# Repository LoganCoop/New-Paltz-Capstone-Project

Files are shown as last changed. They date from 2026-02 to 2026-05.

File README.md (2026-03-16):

# New Paltz Capstone Project – LiDAR Scanner

## Project Ideas
**Date:** 1/21/2026

## Initial Idea
**LiDAR Scanner – Physical Computing**
- Raspberry Pi – Python or Arduino – C++
- Made for room scanning
- Environmental mapping
- Handheld and/or mobile
- 3D printed parts

## Overview
My current idea for the student-proposed project will be a LiDAR scanner that I will build and program myself. I want to use Arduino and/or Raspberry Pi parts for the hardware, as well as 3D printed parts to create housing for the Arduino components. I intend to write the software myself for the LiDAR mapping using the C++-based Arduino language, and/or using Python via a Raspberry Pi. As an add-on to this project, I'd like to make the scanner mobile if I have the time to do so, whether it is done via a drone or a handheld scanner. I believe that this project is a great blend of software and hardware and that it would be a great opportunity to develop my skills in combining both fields of technology. I personally have great experience with CAD and 3D printing, as well as all of the material I have covered during my time working on my computer science degree, so I believe this project would be a great way to improve and show my skills.

## Project Scope
1. **Coordinate Transformation:** Implementing the trigonometric algorithms necessary to map 1D distance readings into 3D space.
2. **Hardware-Software Integration:** Managing the “logic flow” between physical movement (motors) and data acquisition (sensors) to ensure sub-centimeter accuracy.
3. **Signal Processing:** Implementing filters to reduce sensor noise and handle “outlier” data points in complex environments.
4. **Mobility (Stretch Goal):** If time permits, the system will be adapted into a handheld form factor using an IMU (Inertial Measurement Unit) to allow for mobile scanning (SLAM – Simultaneous Localization and Mapping).
	- A Pi Camera 3 can be used for marker-based localization to reduce drift.

## Timeline Layout
- **Phase 1:** Component testing and basic 2D mapping.
- **Phase 2:** Integration of the Godot visualization and 3D data collection.
- **Phase 3:** Refinement of the visualization UI and final housing assembly.

## Initial TF-Luna UART Test
This project includes a small Python script to read TF-Luna frames over UART and print
distance data for quick sensor validation.

### Wiring Notes (TF-Luna to Raspberry Pi)
- Connect GND to GND.
- Connect TF-Luna TX to Pi RX (GPIO 15).
- Connect TF-Luna RX to Pi TX (GPIO 14).
- Provide 5V power to the TF-Luna (verify your model's voltage/logic levels in its datasheet).

### Setup
1. Enable the Pi UART (raspi-config) and reboot.
2. Install dependencies:
	- `python -m pip install -r requirements.txt`
3. Run the reader:
	- `python tools/tfluna_read.py --port /dev/serial0 --baud 115200`

### Output
Each line includes a timestamp, distance in cm, signal strength, and temperature in C.

## Initial BNO055 Quaternion Test
This project includes a small Python script to read BNO055 quaternion output over I2C.

### Wiring Notes (BNO055 to Raspberry Pi)
- Connect GND to GND.
- Connect VIN to 3.3V or 5V (check your board's regulator specs).
- Connect SDA to GPIO 2 (SDA).
- Connect SCL to GPIO 3 (SCL).

### Setup
1. Enable I2C on the Pi (raspi-config) and reboot.
2. Install dependencies:
	- `python -m pip install -r requirements.txt`
3. Run the reader:
	- `python tools/bno055_quat_read.py --address 0x28 --rate 10`

### Output
Each line includes a timestamp and quaternion components (qw, qx, qy, qz).

## Pi Prep Checklist
- Update packages and reboot after updates.
- Enable UART (disable serial console), I2C, and Camera in raspi-config.
- Install base tools: python3-venv, python3-pip, i2c-tools, libcamera-apps.
- Add your user to dialout for serial access and log out/in.

## Pi Camera 3 Tests and Marker Localization
Marker-based localization uses the Pi Camera 3 to detect known visual markers and provide
absolute reference points, which helps reduce drift compared to IMU-only integration.

### Camera Test
1. Install camera tools:
	- `sudo apt install -y python3-picamera2 libcamera-apps`
2. Run the test capture:
	- `python tools/camera_test.py --output camera_test.jpg`

### ArUco Marker Demo
1. Install dependencies:
	- `sudo apt install -y python3-opencv python3-picamera2`
2. Run marker detection:
	- `python tools/aruco_pose_demo.py --rate 10`

---

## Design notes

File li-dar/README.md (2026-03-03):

# LiDAR Quest 3 VR Point Cloud Visualization

This is a **Godot 4.x** project for visualizing LiDAR point clouds in VR using the Meta Quest 3 headset.

## 🎯 Purpose

This VR application replaces the original PiCam 3 approach with Quest 3's superior tracking capabilities, allowing for more accurate and immersive 3D point cloud visualization.

## 📁 Project Structure

```
li-dar/
├── materials/              # Custom materials for rendering
│   └── point_cloud_material.tres
├── scenes/                 # Godot scene files
│   └── main_vr.tscn       # Main VR scene
├── scripts/                # GDScript files
│   ├── lidar_udp_receiver.gd
│   ├── point_cloud_visualizer.gd
│   └── vr_controller.gd
├── shaders/                # Custom shaders
│   └── point_cloud.gdshader
├── icon.svg                # Project icon
├── project.godot           # Godot project configuration
├── QUEST3_VR_SETUP_GUIDE.md    # Complete setup instructions
└── QUEST3_QUICK_START.md        # Quick start checklist
```

## 🚀 Quick Start

1. **Install Godot 4.3+** from [godotengine.org](https://godotengine.org)
2. **Open this project** in Godot
3. **Connect Quest 3** via USB (Developer Mode enabled)
4. **Export to Quest 3** (Project → Export → Android)
5. **Run Python sensor scripts** from parent directory
6. **Launch the app** on Quest 3

**Full instructions**: See [QUEST3_VR_SETUP_GUIDE.md](QUEST3_VR_SETUP_GUIDE.md)

## 🎮 Features

- ✅ Real-time LiDAR point cloud visualization in VR
- ✅ UDP receiver for TFLuna + BNO055 sensor data
- ✅ Mesh-based rendering (up to 50,000 points)
- ✅ Spatial deduplication for cleaner clouds
- ✅ Color-coded distance visualization
- ✅ VR controller support for navigation
- ✅ 6DOF tracking using Quest 3
- ✅ 90Hz refresh rate
- ✅ Custom point cloud shader

## 🔗 How It Connects to Parent Project

This Godot project receives data from:
- **`tools/send_sensor_data_udp.py`** - Sends sensor data via UDP
- **`hal/`** - Hardware abstraction layer for sensors
- **TFLuna LiDAR sensor** - Distance measurements
- **BNO055 IMU** - Orientation quaternions

## 🛠️ Requirements

- **Meta Quest 3** VR headset
- **Godot 4.3+**
- **Android SDK & NDK**
- **Python 3.x** (for sensor scripts)
- **WiFi network** (PC and Quest 3 must be on same network)

## 📚 Documentation

- **[QUEST3_VR_SETUP_GUIDE.md](QUEST3_VR_SETUP_GUIDE.md)** - Complete setup guide
- **[QUEST3_QUICK_START.md](QUEST3_QUICK_START.md)** - Quick start checklist
- **[../UNITY_SETUP_GUIDE.md](../UNITY_SETUP_GUIDE.md)** - Original Unity version (alternative)

## 🎨 Customization

### Change Point Size
Edit `shaders/point_cloud.gdshader`:
```gdshader
uniform float point_size = 8.0;  // Change this value
```

### Change Colors
Edit `scripts/point_cloud_visualizer.gd`:
```gdscript
@export var min_color: Color = Color(0, 0, 1)  # Blue
@export var max_color: Color = Color(1, 0, 0)  # Red
```

## 🐛 Troubleshooting

**No points appearing?**
- Check UDP port 5005 is open in firewall
- Verify Python scripts are running
- Ensure PC and Quest 3 are on same WiFi

**Low frame rate?**
- Reduce `max_points` to 30000
- Increase `voxel_size` to 0.05
- Disable deduplication temporarily

**App crashes?**
- Check Godot console for errors
- Verify Android export templates installed
- Update Quest 3 firmware

## 🎯 Advantages Over Unity/PiCam Approach

1. **No camera required** - Uses Quest 3's built-in tracking
2. **More accurate** - Inside-out tracking beats IMU-only
3. **Real-time immersion** - See the scan as you create it
4. **6DOF freedom** - Walk around the point cloud
5. **No Aruco markers** - Simpler setup
6. **Higher refresh** - 90Hz vs typical 60Hz

## 📊 Performance

- **Target**: 90 FPS on Quest 3
- **Max Points**: 50,000 (configurable)
- **Latency**: < 50ms from sensor to display
- **Resolution**: 1832×1920 per eye

## 🔮 Future Enhancements

- [ ] Point cloud export to PLY/OBJ
- [ ] Multiple TFLuna sensor support
- [ ] Hand tracking instead of controllers
- [ ] Spatial anchors for persistent clouds
- [ ] WiFi direct instead of UDP broadcast

---

**Created**: March 2026  
**Godot Version**: 4.3+  
**Target Platform**: Meta Quest 3 (Android)  
**License**: See parent project

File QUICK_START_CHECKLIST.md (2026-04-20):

# 🎯 Unity LiDAR Scanner - Quick Start Checklist

Follow these steps in order. Check off each step as you complete it.

## ☑️ Phase 1: Project Setup (5 minutes)

- [ ] Open Unity Hub
- [ ] Create new 3D project OR open existing project
- [ ] Create folder structure:
  - [ ] Assets/Scripts/
  - [ ] Assets/Shaders/
  - [ ] Assets/Materials/
  - [ ] Assets/Prefabs/
  - [ ] Assets/Scenes/

## ☑️ Phase 2: Import Files (3 minutes)

- [ ] Copy `LidarUdpReceiver.cs` → `Assets/Scripts/`
- [ ] Copy `SimpleCamera.cs` → `Assets/Scripts/`
- [ ] Copy `PointCloud.shader` → `Assets/Shaders/`
- [ ] Wait for Unity to compile (check bottom-right progress bar)
- [ ] Verify no errors in Console window (Ctrl+Shift+C)

## ☑️ Phase 3: Create Materials (2 minutes)

- [ ] Navigate to `Assets/Shaders/` in Project window
- [ ] Right-click `PointCloud.shader` → Create → Material
- [ ] Rename material to: `PointCloudMaterial`
- [ ] Select material, set in Inspector:
  - [ ] Point Size: `8`
  - [ ] Brightness: `1.0`
- [ ] Move material to `Assets/Materials/` folder

## ☑️ Phase 4: Create Point Prefab (3 minutes)
*(Skip if using mesh-based mode)*

- [ ] Hierarchy → Right-click → 3D Object → Sphere
- [ ] Rename to: `LidarPoint`
- [ ] In Inspector, remove Sphere Collider component
- [ ] Drag from Hierarchy → `Assets/Prefabs/` folder
- [ ] Delete from Hierarchy (prefab is saved)

## ☑️ Phase 5: Setup Scene (10 minutes)

### Create Scanner GameObject:
- [ ] Hierarchy → Right-click → Create Empty
- [ ] Rename to: `LidarScanner`
- [ ] Position: `(0, 0, 0)`
- [ ] Add Component → `LidarUdpReceiver`

### Configure LidarUdpReceiver:
- [ ] **Port**: `5005`
- [ ] **Point Prefab**: Drag from Prefabs folder *(optional)*
- [ ] **Scale Meters**: `0.01`
- [ ] **Point Scale**: `0.02`
- [ ] **Max Points**: `50000`

#### Distance Gradient:
- [ ] Click gradient bar
- [ ] Add color stops:
  - [ ] Left (0%) = Blue
  - [ ] Middle (50%) = Green  
  - [ ] Right (100%) = Red

#### Settings:
- [ ] **Min Distance Meters**: `0.1`
- [ ] **Max Distance Meters**: `5.0`
- [ ] **Min Strength**: `100`
- [ ] **Distance Median Window**: `5`
- [ ] **Orientation Smoothing**: `0.5`

#### Checkboxes:
- [ ] ✅ Use Pos Field
- [ ] ✅ Debug Overlay
- [ ] ✅ Data Already In Unity Frame
- [ ] ⬜ Flip X
- [ ] ⬜ Flip Y
- [ ] ⬜ Swap Y And Z
- [ ] ⬜ Invert Z
- [ ] ⬜ Mirror Horizontal
- [ ] ✅ Use Spatial Deduplication
- [ ] **Voxel Size**: `0.03`
- [ ] ✅ Use Mesh Renderer
- [ ] **Point Cloud Material**: Drag from Materials folder

#### Legacy correction values:
- [ ] **Yaw Correction Degrees**: `0`
- [ ] **Pitch Correction Degrees**: `0`
- [ ] **Roll Correction Degrees**: `0`
- [ ] **Apply Coordinate Correction To Fallback Direction**: unchecked
- [ ] **Invert Fallback Vertical Axis**: unchecked

#### Unity-frame trim (when data is inverted):
- [ ] **Unity Frame Invert X**: checked *(for left/right reversed)*
- [ ] **Unity Frame Invert Y**: checked *(for up/down reversed)*
- [ ] **Unity Frame Invert Z**: unchecked
- [ ] **Unity Frame Yaw Correction Degrees**: `0`
- [ ] **Unity Frame Pitch Correction Degrees**: `0`
- [ ] **Unity Frame Roll Correction Degrees**: `180` *(use this when both left/right and up/down are inverted)*

### Setup Camera:
- [ ] Select `Main Camera` in Hierarchy
- [ ] Position: `(0, 2, -3)`
- [ ] Rotation: `(20, 0, 0)`
- [ ] Background color: Dark gray `(30, 30, 30)`
- [ ] Add Component → `SimpleCamera` *(optional)*

### Lighting:
- [ ] Verify `Directional Light` exists
- [ ] Rotation: `(50, -30, 0)`

### Save Scene:
- [ ] File → Save As → `Assets/Scenes/LidarScanner.unity`

## ☑️ Phase 6: Test Python Connection (5 minutes)

### Start Python Scripts:
- [ ] Open PowerShell/Terminal
- [ ] Navigate to project folder:
  ```powershell
  cd "C:\Users\lpcoo\OneDrive\Desktop\Capstone Project - LiDAR"
  ```
- [ ] Run sensor scripts:
  ```powershell
  python run_all_components.py
  ```
  OR
  ```powershell
  python tools/send_sensor_data_udp.py --ip <QUEST_OR_PC_IP>
  ```
- [ ] Keep the Python sender mount defaults unless you physically remount the IMU/LiDAR assembly.
- [ ] Verify output shows "Sending UDP packets..."

## ☑️ Phase 7: First Test Run! (2 minutes)

- [ ] Press **Play ▶️** in Unity
- [ ] Check top-left overlay shows:
  - [ ] UDP packets count increasing
  - [ ] "Last packet: X.XXs ago" updating
  - [ ] Point count increasing
- [ ] Verify points appearing in Game view
- [ ] Test camera controls (Right-click + WASD)
- [ ] Press Space to calibrate orientation

## ✅ Success Criteria

You should see:
- ✅ Points appearing in 3D space
- ✅ Colors changing by distance (blue → green → red)
- ✅ UDP packet counter increasing
- ✅ No errors in Console
- ✅ Smooth point cloud building up

## ⚠️ Troubleshooting Quick Fixes

| Problem | Solution |
|---|---|
| No packets received | Check Python script is running, port = 5005 |
| No points visible | Check camera position, Material assigned |
| Errors in Console | Read error message, check file paths |
| Performance slow | Decrease maxPoints to 10000, increase voxelSize to 0.05 |
| Points jumping | Increase orientationSmoothing to 0.8 |

## 📚 Full Documentation

For detailed explanations, see:
- `UNITY_SETUP_GUIDE.md` - Complete step-by-step guide
- `MESH_SYSTEM_SETUP.md` - Mesh rendering system details

## 🎮 Controls Reference

### In Unity Editor:
- **Space** - Calibrate sensor orientation
- **Right-Mouse + WASD** - Fly camera
- **E/Q** - Up/Down
- **Shift** - Move faster
- **F** - Focus on selected object

### In Python:
- **Ctrl+C** - Stop sensor scripts

---

**Estimated Total Time: 30 minutes**

**Current Step:** _________

**Notes:**
_______________________________________________________
_______________________________________________________
_______________________________________________________

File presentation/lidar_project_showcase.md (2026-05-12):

---
marp: true
theme: lidar-showcase
paginate: true
size: 16:9
style: |
  section {
    font-size: 28px;
  }
  .tight li {
    margin: 0.12em 0;
  }
  .center {
    text-align: center;
  }
  .label {
    color: #0b5fff;
    font-weight: 700;
    text-transform: uppercase;
    letter-spacing: 0.08em;
    font-size: 0.52em;
  }
---

<!-- _class: lead -->
# Handheld LiDAR Scanner System
## Custom Sensor Build to Point Cloud Visualization

Logan Cooper  
SUNY New Paltz

<div class="callout">
This project combines hardware integration, Python tooling, networking, CAD and 3D printing, and VR rendering into one working spatial scanning pipeline.
</div>

---

# Why This Project Matters

<div class="columns">
<div class="panel">
<div class="label">Core Idea</div>
Build a low-cost handheld system that turns real-world distance samples into a 3D point cloud.

</div>
<div class="panel">
<div class="label">What It Shows</div>
Physical hardware, embedded-style integration, data processing, visualization, and immersive interaction.
</div>
</div>

<div class="metric-row">
<div class="metric"><strong>Hardware</strong> TF-Luna, BNO055, Pi 5, Pi Camera 3, 3D printed housing</div>
<div class="metric"><strong>Software</strong> Python tools, HAL interfaces, Unity and Godot visualization</div>
<div class="metric"><strong>Outcome</strong> Live UDP stream into a 2D and VR point cloud viewer</div>
</div>

---

# What Is LiDAR?

**LiDAR** stands for **Light Detection and Ranging**.

It works by sending out laser pulses and measuring how long they take to return, which gives distance information that can be used to reconstruct the surrounding environment.

<div class="columns">
<div class="panel">
<strong>Common Uses</strong>
<ul>
  <li>Autonomous navigation</li>
  <li>Robotics and mapping</li>
  <li>Surveying and architecture</li>
  <li>AR and VR spatial computing</li>
</ul>
</div>
<div class="panel">
<strong>Why It Fits This Project</strong>
<ul>
  <li>Strong mix of hardware and software</li>
  <li>Clear real-world application</li>
  <li>Good match for CAD and fabrication work</li>
  <li>Expandable toward mobile scanning and SLAM</li>
</ul>
</div>
</div>

---

# Project Story

> The project began as a custom LiDAR scanner concept and evolved into a working end-to-end system that reads sensors on a Raspberry Pi, transforms the data into 3D points, and visualizes the results inside a Unity/Godot environment and soon into a Quest 3 VR application.

---

<!-- _class: section -->
# Build Components
## Hardware and software pieces that make the system work

---

# System Components and Their Roles

| Component | What it does in the project |
|---|---|
| TF-Luna LiDAR | Captures 1D distance samples from the environment |
| BNO055 IMU | Provides quaternion orientation for 3D point transformation |
| Raspberry Pi 5 | Runs the Python code, sensor acquisition, and UDP transmission |
| Pi Camera 3 | Supported calibration and ArUco marker localization experiments |
| 3D printed housing | Turns the electronics into a handheld scanner form factor |
| Unity / Godot | Receives and visualizes live spatial data |
| Meta Quest 3 | Will make the point cloud explorable in immersive VR |

---

# Software Stack

<div class="columns">
<div class="panel">
<strong>Python Side</strong>
<ul>
  <li>Sensor readers for TF-Luna and BNO055</li>
  <li>Test utilities and data output tools</li>
  <li>UDP sender scripts</li>
  <li>HAL interfaces for cleaner integration and mocking</li>
</ul>
</div>
<div class="panel">
<strong>Visualization Side</strong>
<ul>
  <li>Unity for earlier visualization and marker testing</li>
  <li>Godot 4 project for current VR rendering</li>
  <li>Custom point cloud shader and material pipeline</li>
  <li>Quest 3 deployment and debugging workflow</li>
</ul>
</div>
</div>

<div class="callout">
This split was important: the Pi handles sensing and transformation, while the engine handles rendering and user experience.
</div>

---

# Unity Progress (Completed)

<div class="columns">
<div class="panel">
<strong>What I Finished in Unity</strong>
<ul>
  <li>Built UDP data bridge from Raspberry Pi to Unity</li>
  <li>Validated TF-Luna and BNO055 data flow in real time</li>
  <li>Implemented ArUco marker pose streaming into Unity</li>
  <li>Updated receiver to handle both sensor and marker data</li>
</ul>
</div>
<div class="panel">
<strong>Why This Matters</strong>
<ul>
  <li>Proved core scanner pipeline works end-to-end</li>
  <li>Confirmed packet format and transform logic</li>
  <li>Reduced risk before moving to VR deployment</li>
</ul>
</div>
</div>

---

<!-- _class: section -->
# Main Challenge
## Pi Camera 3 integration issues and project pivot

---

# Pi Camera 3 Challenge and Pivot to VR

<div class="columns">
<div class="panel">
<strong>Problem I Ran Into</strong>
<ul>
  <li>Pi Camera 3 setup was inconsistent across packages/drivers</li>
  <li>Marker pipeline added complexity during live integration</li>
  <li>Troubleshooting consumed time better spent on core scanning workflow</li>
</ul>
</div>
<div class="panel">
<strong>Decision and Result</strong>
<ul>
  <li>Kept Unity progress as validated foundation</li>
  <li>Shifted visualization path to Quest 3 VR pipeline</li>
  <li>Simplified interactive inspection of point clouds</li>
</ul>
</div>
</div>

<div class="callout">
The switch to VR was a strategic project decision, not a reset: it built on the data pipeline already proven in Unity.
</div>

---

<!-- _class: section -->
# Construction
## Wiring, CAD, printing, and assembly

---

# How the Scanner Was Built

<div class="columns">
<div>

1. Wire the TF-Luna to the Raspberry Pi over UART.
2. Wire the BNO055 IMU to the Raspberry Pi over I2C.
3. Verify the hardware with isolated test scripts.
4. Design the handheld housing in CAD.
5. 3D print and assemble the casing.
6. Re-test as an integrated scanner system.

</div>
<div>

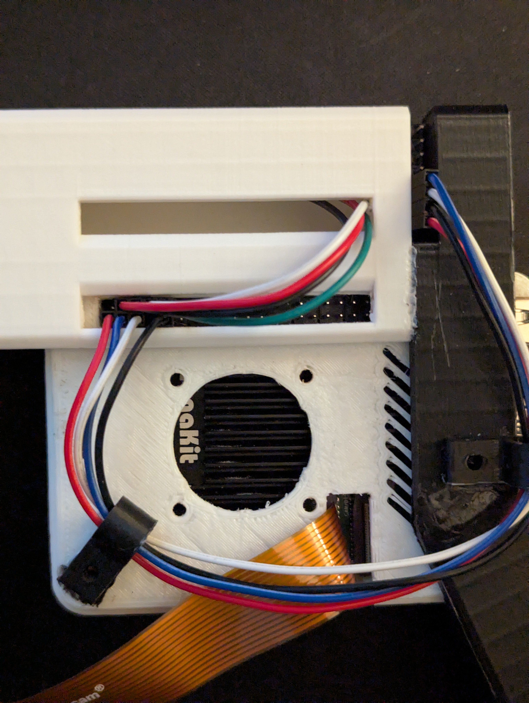
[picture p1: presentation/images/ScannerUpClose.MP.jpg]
height:260px


</div>
</div>

<div class="callout">
The housing design was made to keep sensor alignment stable and make the device practical for handheld scanning.
</div>

---

# Data Pipeline Architecture

```text
TF-Luna distance  ----->
                        Raspberry Pi 5 -----> UDP packets -----> Unity / Godot / Quest 3
BNO055 quaternion ----->
```

<div class="columns">
<div class="panel">
<strong>On the Raspberry Pi</strong>
<ul>
  <li>Read live sensor data</li>
  <li>Pair orientation with distance samples</li>
  <li>Transform measurements into 3D point candidates</li>
</ul>
</div>
<div class="panel">
<strong>In the Visualization Engine</strong>
<ul>
  <li>Receive incoming packets</li>
  <li>Add points to the cloud buffer</li>
  <li>Render them in real time for inspection</li>
</ul>
</div>
</div>

---

<!-- _class: section -->
# Initial Testing
## Proving each part worked before full integration

---

# Testing Approach

The project was built incrementally.

<div class="columns">
<div class="panel tight">
<strong>Hardware Validation</strong>
<ul>
  <li>TF-Luna UART test</li>
  <li>BNO055 quaternion test</li>
  <li>Pi Camera 3 image capture test</li>
  <li>Camera calibration and ArUco experiments</li>
</ul>
</div>
<div class="panel tight">
<strong>Integration Validation</strong>
<ul>
  <li>UDP stream testing</li>
  <li>Unity marker pose visualization</li>
  <li>Transition plan into Godot VR receiver</li>
  <li>Initial Quest 3 pipeline validation</li>
</ul>
</div>
</div>

<div class="callout">
Testing components in isolation first made it easier to find wiring, configuration, and data-format issues quickly.
</div>

---

# Raw Sensor Output Examples

<div class="columns">
<div>

### TF-Luna sample
```text
1770662039.648 dist_cm=0 strength=128 temp_c=39.00
1770662039.658 dist_cm=0 strength=128 temp_c=39.00
1770662039.669 dist_cm=0 strength=131 temp_c=39.00
```

</div>
<div>

### BNO055 sample
```text
1770662963.567 qw=1.000000 qx=0.000000 qy=-0.000061 qz=0.000305
1770662963.669 qw=0.368164 qx=-0.492737 qy=0.788452 qz=0.000122
1770662963.771 qw=0.368164 qx=-0.492737 qy=0.788452 qz=0.000183
```

</div>
</div>

<div class="caption">These logs show the actual raw information the project uses: distance, strength, temperature, and orientation quaternion data.</div>

---

<!-- _class: section -->
# Sending Data
## Bridging the scanner to the visualization environment with UDP

---

# Why UDP Was a Good Fit

<div class="columns">
<div class="panel">
<strong>Advantages</strong>
<ul>
  <li>Lightweight</li>
  <li>Fast for real-time streaming</li>
  <li>Easy to integrate into Unity and Godot</li>
  <li>Good enough even if a small number of packets are lost</li>
</ul>
</div>
<div class="panel">
<strong>What Gets Sent</strong>
<ul>
  <li>Timestamp</li>
  <li>Distance measurements</li>
  <li>Orientation data</li>
  <li>Transformed point information</li>
  <li>Marker or visualization metadata when needed</li>
</ul>
</div>
</div>

```text
Sensor Read -> Orientation Fusion -> Point Transform -> UDP Packet -> Receiver App
```

---

<!-- _class: section -->
# Point Cloud
## Turning sensor samples into a usable 3D representation

---

# System Diagram

<div class="diagram-grid">
<svg viewBox="0 0 1040 600" role="img" aria-label="LiDAR system data flow diagram">
  <defs>
    <marker id="arrow-showcase" viewBox="0 0 10 10" refX="8" refY="5" markerWidth="8" markerHeight="8" orient="auto-start-reverse">
      <path d="M 0 0 L 10 5 L 0 10 z" fill="#3f7bff"></path>
    </marker>
  </defs>

  <rect class="entity" x="24" y="80" width="110" height="46" rx="10"></rect>
  <text x="79" y="109" text-anchor="middle">Operator</text>

  <rect class="entity" x="24" y="430" width="110" height="46" rx="10"></rect>
  <text x="79" y="459" text-anchor="middle">Sensors</text>

  <ellipse class="process" cx="395" cy="90" rx="120" ry="28"></ellipse>
  <text x="395" y="96" text-anchor="middle">Scanner Control</text>

  <ellipse class="process" cx="395" cy="210" rx="132" ry="30"></ellipse>
  <text x="395" y="216" text-anchor="middle">Sensor Read Process</text>

  <ellipse class="process" cx="395" cy="346" rx="132" ry="30"></ellipse>
  <text x="395" y="352" text-anchor="middle">Pose Fusion Process</text>

  <ellipse class="process" cx="395" cy="492" rx="142" ry="30"></ellipse>
  <text x="395" y="498" text-anchor="middle">Point Cloud Rendering</text>

  <rect class="store-body" x="820" y="38" width="130" height="98" rx="2"></rect>
  <ellipse class="store-top" cx="885" cy="38" rx="65" ry="18"></ellipse>
  <ellipse class="store-top" cx="885" cy="136" rx="65" ry="18"></ellipse>
  <text x="885" y="46" text-anchor="middle">Control State</text>

  <rect class="store-body" x="780" y="168" width="170" height="130" rx="2"></rect>
  <ellipse class="store-top" cx="865" cy="168" rx="85" ry="22"></ellipse>
  <ellipse class="store-top" cx="865" cy="298" rx="85" ry="22"></ellipse>
  <text x="865" y="175" text-anchor="middle">Raw Scan Samples</text>

  <rect class="store-body" x="810" y="330" width="140" height="104" rx="2"></rect>
  <ellipse class="store-top" cx="880" cy="330" rx="70" ry="19"></ellipse>
  <ellipse class="store-top" cx="880" cy="434" rx="70" ry="19"></ellipse>
  <text x="880" y="337" text-anchor="middle">Pose Records</text>

  <rect class="store-body" x="790" y="466" width="160" height="112" rx="2"></rect>
  <ellipse class="store-top" cx="870" cy="466" rx="80" ry="21"></ellipse>
  <ellipse class="store-top" cx="870" cy="578" rx="80" ry="21"></ellipse>
  <text x="870" y="473" text-anchor="middle">Point Cloud Buffer</text>

  <path class="connector" d="M 134 103 C 205 103, 250 95, 276 92" marker-end="url(#arrow-showcase)"></path>
  <path class="connector" d="M 134 103 C 205 115, 250 178, 263 205" marker-end="url(#arrow-showcase)"></path>
  <path class="connector" d="M 134 103 C 205 145, 244 430, 252 486" marker-end="url(#arrow-showcase)"></path>

  <path class="connector" d="M 134 453 C 205 453, 243 436, 257 358" marker-end="url(#arrow-showcase)"></path>
  <path class="connector" d="M 134 453 C 215 453, 238 483, 251 492" marker-end="url(#arrow-showcase)"></path>

  <path class="connector" d="M 515 90 C 635 90, 712 90, 820 64" marker-end="url(#arrow-showcase)"></path>
  <path class="connector" d="M 527 210 C 637 210, 701 210, 780 233" marker-end="url(#arrow-showcase)"></path>
  <path class="connector" d="M 527 346 C 636 346, 716 346, 810 382" marker-end="url(#arrow-showcase)"></path>
  <path class="connector" d="M 537 492 C 634 492, 708 500, 790 520" marker-end="url(#arrow-showcase)"></path>

  <path class="connector" d="M 820 120 C 714 130, 618 180, 515 205" marker-end="url(#arrow-showcase)"></path>
  <path class="connector" d="M 790 520 C 708 512, 618 438, 515 358" marker-end="url(#arrow-showcase)"></path>
  <path class="connector" d="M 810 382 C 714 386, 621 448, 525 487" marker-end="url(#arrow-showcase)"></path>
</svg>
</div>

<div class="callout">
This version frames the project as a data-flow system: external inputs feed processing stages, which update stored scan state and the final point cloud buffer.
</div>

---

# VR Transition

<div class="columns">
<div class="panel">
<strong>Earlier Stage</strong>
<ul>
  <li>Unity-based environment</li>
  <li>Marker pose visualization</li>
  <li>Desktop validation of data flow</li>
  <li>Good for early debugging and proof of concept</li>
</ul>
</div>
<div class="panel">
<strong>Current Direction</strong>
<ul>
  <li>Dedicated Godot VR pipeline</li>
  <li>Quest 3 deployment workflow</li>
  <li>In-headset point cloud viewing</li>
  <li>Focused scan analysis in VR</li>
</ul>
</div>
</div>

---

# Why VR Still Improves the Project

- Depth is easier to understand in an immersive 3D view.
- You can move around the point cloud naturally.
- It is easier to notice gaps, noise, and structure.
- It builds directly on the Unity-validated data pipeline.

---

# Housing Design and Assembly

<div class="columns">
<div>

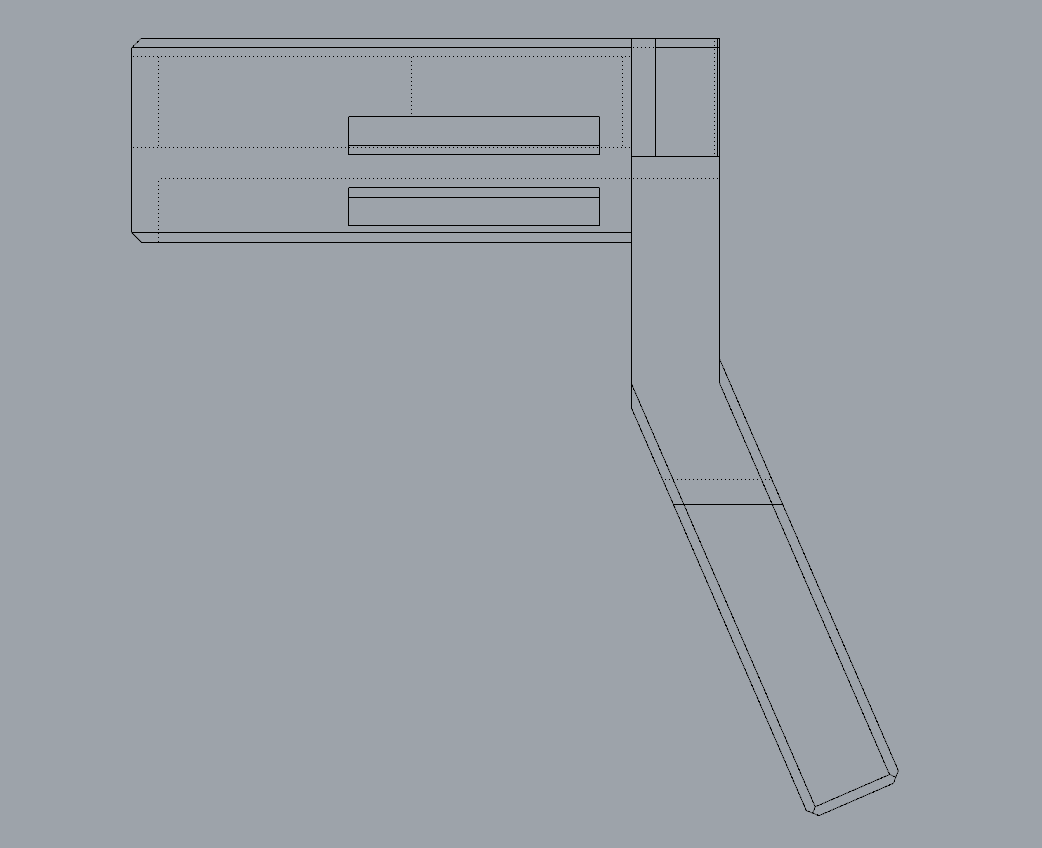
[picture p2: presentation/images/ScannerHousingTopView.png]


</div>
<div>

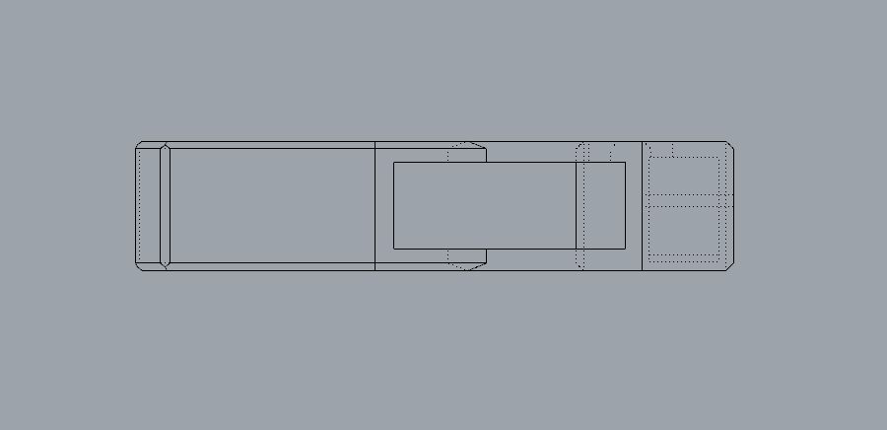
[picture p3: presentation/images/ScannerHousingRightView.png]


</div>
</div>

- Front, top, and side housing views were used to verify fit and assembly clearances.
- The enclosure organizes TF-Luna, BNO055, and Raspberry Pi mounting points.
- Mechanical alignment improved repeatability during scan motion.
- CAD to print to test iteration shortened integration time.

<div class="caption">The 3D-printed housing acts as the mechanical backbone of the handheld scanner.</div>

---

# Project Timeline and Growth

| Date | Milestone |
|---|---|
| 1/21/26 | Initial project idea and scope defined |
| 2/5/26 | Planned addition of IMU, camera, and integration hardware |
| 2/6/26 | Core components assembled and initial testing underway |
| 2/9/26 | Housing design and Unity bridge work began |
| 2/12/26 | Pi Camera 3 calibration and ArUco pose streaming to Unity completed |
| 3/3/26 | Switched to dedicated Godot Quest 3 VR pipeline |
| 3/10/26 | Added VR scripts, Quest deployment flow, and improved point cloud rendering |

---

<!-- _class: section -->
# Conclusion
## What this project demonstrates today

---

# What This Project Already Achieved

- Built a custom handheld LiDAR scanner system from separate components
- Combined hardware, Python tooling, networking, CAD, and 3D visualization
- Created a working live Unity pipeline from sensors to point cloud display
- Identified and handled integration challenges (including Pi Camera 3 issues)
- Established a clear transition path from Unity validation to VR interaction

---

# Next Steps

<div class="columns">
<div class="panel">
<strong>Technical Improvements</strong>
<ul>
  <li>Finalize end-to-end Quest 3 benchmark</li>
  <li>Add point cloud export support</li>
  <li>Continue filtering/calibration improvements</li>
</ul>
</div>
<div class="panel">
<strong>User Experience Improvements</strong>
<ul>
  <li>Basic controller interactions in VR</li>
  <li>Simple reset/toggle tools</li>
  <li>Polished in-headset debug HUD</li>
</ul>
</div>
</div>

---

<!-- _class: lead -->
# Questions?

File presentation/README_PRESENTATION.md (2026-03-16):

# Presentation Files

## Main Deck
- `lidar_project_showcase.md`

## Theme
- `lidar-showcase-theme.css`

## Best way to use it
This deck is written for **Marp** in VS Code.

### In VS Code
1. Install the **Marp for VS Code** extension if you do not already have it.
2. Open `lidar_project_showcase.md`.
3. Open the Marp preview.
4. Export to PDF, HTML, or PowerPoint if desired.

## Suggested image folder
Put your presentation images here if you want them added into the slides later:
- `presentation/images/`

Suggested filenames:
- `hardware_wiring.jpg`
- `cad_housing.png`
- `printed_housing.jpg`
- `unity_view.png`
- `quest3_pointcloud.png`

## Notes
- The deck is based on the project story and milestones from `README.md` and `DIARY.md`.
- The visual theme is designed to feel warm, polished, and technical without looking generic.
- The VR direction reflects the current Quest 3 black-background, non-passthrough setup.

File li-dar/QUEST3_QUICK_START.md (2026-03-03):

# Quest 3 VR LiDAR - Quick Start Checklist

## ✅ Before You Start
- [ ] Quest 3 fully charged
- [ ] Quest 3 Developer Mode enabled (via Meta Quest app)
- [ ] PC and Quest 3 on same WiFi network
- [ ] Godot 4.3+ installed
- [ ] Android export templates installed in Godot
- [ ] ADB (Android Debug Bridge) installed
- [ ] LiDAR sensors (TFLuna + BNO055) connected
- [ ] Python environment set up

---

## 🔧 Hardware Setup (5 minutes)
1. [ ] Connect TFLuna to PC/Raspberry Pi via UART/I2C
2. [ ] Connect BNO055 to same device via I2C
3. [ ] Verify sensor connections:
   ```powershell
   python tools/tfluna_read.py
   python tools/bno055_quat_read.py
   ```
4. [ ] Connect Quest 3 to PC via USB-C cable (for first deployment)
5. [ ] Put on Quest 3 and allow USB debugging

---

## 💻 Software Setup (10 minutes)

### Network Configuration
1. [ ] Get PC IP address: `ipconfig` in PowerShell
2. [ ] Note down IP (e.g., 192.168.1.100)
3. [ ] Open Windows Firewall and allow UDP port 5005:
   ```powershell
   netsh advfirewall firewall add rule name="LiDAR UDP" dir=in action=allow protocol=UDP localport=5005
   ```

### Godot Project
1. [ ] Open Godot 4.3
2. [ ] Import project: `li-dar\project.godot`
3. [ ] Wait for project to load and import assets
4. [ ] Open `scenes/main_vr.tscn`

### Export Configuration
1. [ ] Go to **Project → Export**
2. [ ] Add **Android** preset
3. [ ] Configure for Quest 3:
   - [ ] XR Mode: OpenXR
   - [ ] Permissions: INTERNET, ACCESS_NETWORK_STATE
   - [ ] Hand Tracking: V2.0
4. [ ] Verify ADB connection: `adb devices`

---

## 🚀 First Run (5 minutes)

### Start Sensor Streaming
1. [ ] Open PowerShell in project root
2. [ ] Run UDP streaming:
   ```powershell
   python tools/send_sensor_data_udp.py
   ```
   OR
   ```powershell
   python run_all_components.py
   ```
3. [ ] Verify terminal shows "Sending UDP packets..."

### Deploy to Quest 3
1. [ ] In Godot, click **Project → Export → Quest 3**
2. [ ] Click **Export Project** → Save as `lidar_quest3.apk`
3. [ ] OR click **Remote Debug** to auto-deploy
4. [ ] Wait for build to complete (1-3 minutes first time)
5. [ ] App should auto-launch on Quest 3

---

## 🎮 Testing (2 minutes)

### In Quest 3
1. [ ] Put on Quest 3 headset
2. [ ] Look around - you should see empty 3D space
3. [ ] Check console output (if using Remote Debug):
   - [ ] "✓ UDP Receiver started on port 5005"
   - [ ] "✓ Point Cloud Visualizer connected"

### Generate Point Cloud
1. [ ] Point TFLuna sensor at objects around you
2. [ ] Slowly rotate or move the sensor
3. [ ] Watch as colored points appear in VR space
4. [ ] Points should be:
   - Blue = close objects
   - Red = far objects
   - Updating in real-time

### Controller Test
1. [ ] **Left thumbstick**: Move forward/back/strafe
2. [ ] **Left grip + thumbstick X**: Rotate view
3. [ ] **Left grip + trigger**: Scale point cloud up
4. [ ] **Left trigger click**: Recenter player
5. [ ] **Left X/A button**: Toggle spatial deduplication
6. [ ] **Left Y/B button**: Clear point cloud
7. [ ] **Left Menu button**: Toggle HUD visibility

---

## 🐛 Quick Troubleshooting

### No Point Cloud Appearing
- [ ] Check Python script is running and sending UDP
- [ ] Verify firewall allows UDP 5005
- [ ] Ensure PC IP is correct
- [ ] Check both devices on same WiFi network
- [ ] Look at Godot console for UDP errors

### App Crashes or Won't Launch
- [ ] Check Godot console for export errors
- [ ] Verify Android export templates installed
- [ ] Ensure Quest 3 firmware is up to date
- [ ] Try clean build: delete `build` folder and re-export

### Low Frame Rate
- [ ] Reduce Max Points (50000 → 30000)
- [ ] Increase Voxel Size (0.03 → 0.05)
- [ ] Disable shadows on DirectionalLight3D
- [ ] Enable Foveated Rendering (already enabled)

### Controller Not Working
- [ ] Check Quest 3 controllers are paired
- [ ] Replace controller batteries if needed
- [ ] Verify controller tracking in Quest dashboard

---

## 📊 Expected Results

After completing this checklist, you should have:
- ✓ Real-time 3D point cloud in VR
- ✓ Color-coded distance visualization
- ✓ Smooth 90Hz VR experience
- ✓ Full 6DOF movement around point cloud
- ✓ Working controller input
- ✓ Up to 50,000 points rendered

---

## 🎯 Next Steps

Once basic functionality works:
1. [ ] Calibrate BNO055 for better orientation
2. [ ] Tune point cloud colors and size
3. [ ] Experiment with voxel size for quality vs performance
4. [ ] Add multiple TFLuna sensors for faster scanning
5. [ ] Implement point cloud export to PLY/OBJ format

---

## 📝 Notes

**UDP Reception Test:**
```gdscript
# In Godot console, you should see:
UDP Receiver started on port 5005
✓ Point Cloud Visualizer connected to UDP Receiver
Packet received: TFLuna distance: 1.23m, Strength: 450
```

**Performance Target:**
- 90 FPS on Quest 3 with 30k-50k points
- < 20ms frame time
- Stereo rendering at 1832x1920 per eye

---

**Time to Complete**: ~20-25 minutes for full setup
**Difficulty**: Intermediate
**Last Updated**: March 2026

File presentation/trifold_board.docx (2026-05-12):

01 What Is LiDAR?

Understanding the core sensing technology behind this project

DEFINITION

LiDAR stands for Light Detection and Ranging. It works by emitting laser pulses and measuring the time it takes for each pulse to bounce back from a surface. That travel time is converted into a precise distance measurement — the same principle as sonar, but using light instead of sound.

HOW A DISTANCE READING BECOMES A 3D POINT

- The sensor fires a laser and measures the round-trip time to the target.
- Distance (d) is calculated: d = (c × t) / 2
- An orientation reading (from the IMU) provides a direction vector.
- Together they place a point in 3D space: (x, y, z)
- Thousands of these points build a point cloud — a 3D map.

REAL-WORLD USES

- Self-driving cars
- Robotics & navigation
- Architecture & surveying
- Forestry & geology
- AR/VR spatial computing
- Archaeology

▶ This project makes LiDAR accessible at low cost — from a $30 sensor to a live interactive 3D point cloud.

KEY STATS

- Sample rate: 250 Hz
- Effective range: 0.2 – 8 m
- Typical accuracy: ±2 cm
- Output: 3D point cloud

02 Hardware Components

Every physical part of the scanner and what it contributes

TF-Luna LiDAR | Measures distance via time-of-flight laser [UART (serial)] 250 Hz, 0.2–8 m; returns dist, signal strength & temp

BNO055 IMU | Provides 9-DOF orientation as a quaternion for point direction [I²C (bus 1)] On-board sensor fusion; outputs qw, qx, qy, qz directly

Raspberry Pi 5 | Central compute — reads sensors, processes data, sends UDP [GPIO / USB] Runs Python tools, hosts the HAL, streams to visualization

Pi Camera Rev 1.3 | Detects ArUco visual markers for precise scanner positioning [CSI ribbon] Used with OpenCV for pose estimation; replaced Pi Camera 3

3D Printed Housing | Holds all electronics in a stable handheld form factor [—] Designed in Rhino 3D; maintains sensor alignment during scans

ArUco Markers | Visual reference points to anchor the scanner in space [Camera] Reduce IMU drift; provide absolute position in the scene

▶ Each component was validated with isolated Python test scripts before full integration — catching wiring and config issues early.

TOTAL COMPONENT COST

TF-Luna (~$30), BNO055 breakout (~$10), Raspberry Pi 5 (~$80), Pi Camera (~$25). The system proves that capable spatial scanning does not require expensive commercial hardware.

03 Physical Construction

Wiring, CAD design, 3D printing, and final assembly

WIRING THE SCANNER

- TF-Luna → Pi UART: TX→RX (GPIO 14/15), 5 V power & GND
- BNO055 → Pi I²C: SDA (GPIO 2), SCL (GPIO 3), 3.3 V & GND
- Pi Camera: CSI ribbon connector to Pi 5 camera port
- UART and I²C enabled in raspi-config; serial console disabled
- User added to dialout group for serial port access

CAD & 3D PRINTING

- Housing modeled in Rhino 3D (.3dm files)
- Designed to hold TF-Luna, BNO055, Pi 5, and camera together
- Sensor alignment baked into the geometry — no re-calibration needed after assembly
- Printed while software development ran in parallel to save time

ASSEMBLY STEPS

- Step 1: Wire TF-Luna to Pi and validate with tfluna_read.py
- Step 2: Wire BNO055 to Pi and validate with bno055_quat_read.py
- Step 3: Connect Pi Camera and verify image capture
- Step 4: Run camera calibration and capture ArUco marker images
- Step 5: Install components into 3D printed housing
- Step 6: Re-run all sensor tests as an integrated unit

▶ The housing was designed so the LiDAR sensor, IMU, and camera maintain a fixed spatial relationship — making orientation math between sensors consistent.

04 Software Architecture

Python tools, HAL interfaces, and the visualization stack

PYTHON SIDE (RASPBERRY PI)

- HAL (Hardware Abstraction Layer) — clean interfaces; any sensor can be swapped or mocked without changing other code
- tfluna_read.py — UART reader for raw distance frames
- bno055_quat_read.py — I²C reader for quaternion orientation
- aruco_pose_demo.py — camera-based marker detection and pose estimation
- send_sensor_data_udp.py — fuses all sensor streams and broadcasts UDP packets

TESTING & MOCKING

- All HAL interfaces have mock implementations for offline testing
- tests/test_hal.py verifies sensor logic without hardware
- Mock output logs in test_outputs/ used for data format validation

VISUALIZATION SIDE (UNITY)

- Unity (C#) — rendering target; validated the full data pipeline
- Custom GLSL point cloud shader for real-time rendering
- Debug overlay for live diagnostics during scanning

▶ The HAL design means the scanner's software can be tested on any computer — not just the Pi — which dramatically speeds up development.

DATA FLOW

TF-Luna (UART) ──→ Pi Python tools ──→ Coordinate transform ──→ UDP packet ──→ Unity receiver ──→ Point Cloud render
BNO055 (I²C) ──→ ↗ ArUco Camera ──→ ↗ (scanner origin fusion)

05 Initial Testing

Validating every component before full system integration

TF-LUNA RAW OUTPUT SAMPLE

1770662039.648 dist_cm=0 strength=128 temp_c=39.00
1770662039.658 dist_cm=0 strength=128 temp_c=39.00
1770662039.669 dist_cm=42 strength=131 temp_c=39.00

Each frame includes a Unix timestamp, measured distance, return signal strength (quality), and on-chip temperature.

BNO055 RAW OUTPUT SAMPLE

1770662963.567 qw=1.000 qx=0.000 qy=-0.000 qz=0.000
1770662963.669 qw=0.368 qx=-0.492 qy=0.788 qz=0.000
1770662963.771 qw=0.368 qx=-0.492 qy=0.788 qz=0.000

Quaternions describe full 3D orientation with no gimbal lock. The BNO055's internal fusion removes the need for manual Euler math.

INCREMENTAL TEST STRATEGY

- Each sensor tested in isolation before integration
- Hardware faults caught early via per-component scripts
- UDP stream validated before connecting to Unity
- ArUco pipeline tested independently from IMU stream
- Camera calibration verified with dedicated image capture tool

▶ Testing components separately first eliminated wiring and config issues early, so final integration debugging focused only on software logic.

06 Sending Data with UDP

Bridging the Raspberry Pi scanner to the visualization environment in real time

WHY UDP?

- Low overhead — no handshaking or connection state
- Low latency — packets arrive as fast as the network allows
- Fire-and-forget — acceptable if a few frames are dropped; point clouds are naturally tolerant of gaps
- Easy to receive — Unity and Python both have simple UDP socket APIs

PACKET CONTENTS

- tfluna — distance (cm), signal strength, temperature
- bno055 — quaternion orientation (qw, qx, qy, qz)
- aruco — detected marker IDs and pose vectors (when camera is active)
- scanner_pose — fused position (from ArUco) + orientation (from IMU)
- pos_m — final 3D endpoint in world space, ready to plot

TRANSMISSION PIPELINE

- Pi reads TF-Luna and BNO055 continuously
- ArUco detector sends marker poses to local port 6006
- Aggregator fuses all three streams into one JSON packet
- Packet broadcast to visualization host on port 5005
- Unity receiver parses JSON and queues the new point

▶ The Pi owns the coordinate math. The visualization engine just plots what arrives — keeping the rendering side simple and engine-agnostic.

FRAME MODE TAG

Each packet includes a frame mode tag (unity_frame / raw) so the receiving engine knows whether coordinate conversion has already been applied by the Pi — eliminating double-correction bugs.

07 Point Cloud Generation

Turning raw sensor samples into a navigable 3D spatial map

HOW EACH POINT IS COMPUTED

- 1. Read distance — TF-Luna returns distance d to the nearest surface along the sensor axis.
- 2. Read orientation — BNO055 returns a unit quaternion q describing where the scanner is pointing.
- 3. Build direction vector — rotate the scanner's forward vector (0,0,1) by q to get a world-space direction.
- 4. Compute endpoint — multiply the direction vector by d to get the absolute 3D position of the surface.
- 5. Accumulate — the new point is appended to the cloud buffer and rendered in real time.

COORDINATE SYSTEM CHALLENGES

- TF-Luna, BNO055, and Unity each use different axis conventions
- Iterative live testing used to determine axis flips, swaps, and yaw offsets
- Final calibrated settings: Flip Y, Swap Y↔Z, Invert Z, Yaw correction −180°
- Frame mode tagging prevents double-correction between Pi and engine

RENDERING

- Custom GLSL point cloud shader
- Points colored by depth or height
- GPU-side rendering for performance
- Renders in Unity in real time

▶ ArUco markers improve accuracy by anchoring the scanner's 3D position. Without them, small IMU drift causes scans to 'float' over time.

08 Conclusion & Lessons Learned

What was built, what was gained, and where it goes next

WHAT WAS DELIVERED

- Fully wired handheld LiDAR scanner in a custom 3D printed housing
- Python sensor stack with HAL interfaces and hardware mock support
- ArUco camera pipeline for accurate scanner pose estimation
- UDP sensor fusion stream combining LiDAR, IMU, and camera data
- Unity point cloud viewer — validated end-to-end pipeline

KEY LESSONS

- Test incrementally — isolate components first, integrate second
- Pivot strategically — when a camera driver blocked progress, shifting focus to Unity visualization kept the project moving
- Coordinate systems matter — every engine and sensor has its own axes; mapping them correctly is non-trivial
- Sensor fusion > single-source — combining IMU + ArUco produces far more stable results than either alone

SKILLS DEVELOPED

- Embedded hardware integration (UART, I²C, GPIO)
- Computer vision (camera calibration, ArUco detection)
- 3D math: quaternions, coordinate transforms, point clouds
- Network programming (UDP socket design)
- Game engine development (Unity C#)
- CAD design and 3D printing

▶ This project combined hardware, software, networking, computer vision, and 3D math into a single working pipeline — demonstrating what a computer science education looks like in practice.

FUTURE DIRECTIONS

- SLAM — simultaneous localization and mapping during movement
- Point cloud export and mesh reconstruction
- Smoothed sensor fusion with complementary or Kalman filtering

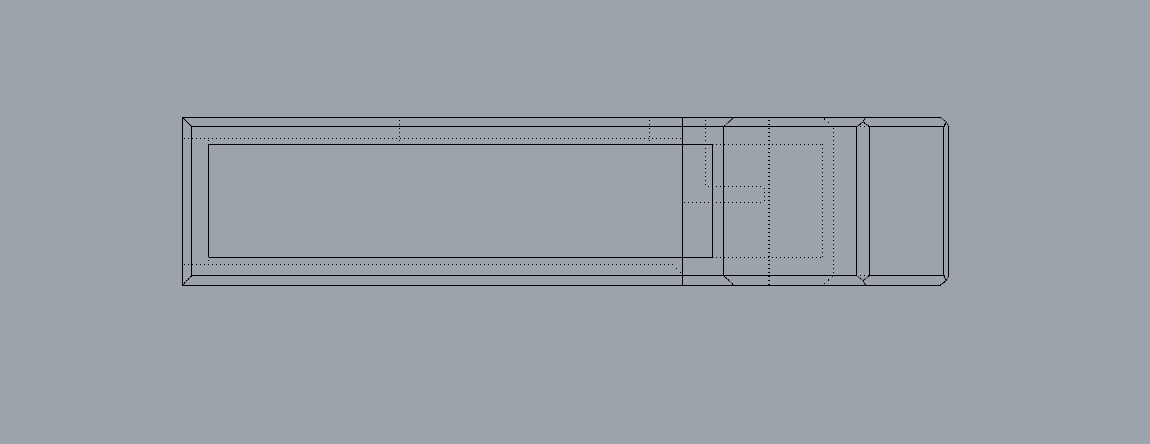
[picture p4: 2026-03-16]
presentation/images/ScannerHousingFrontView.png

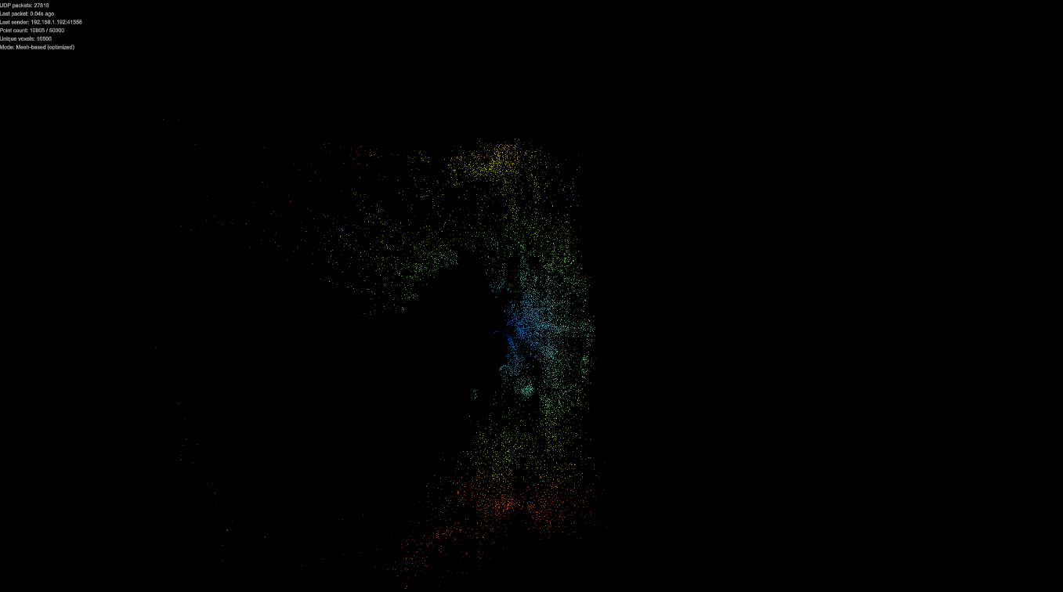
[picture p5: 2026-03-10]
presentation/images/PointCloud_1.png

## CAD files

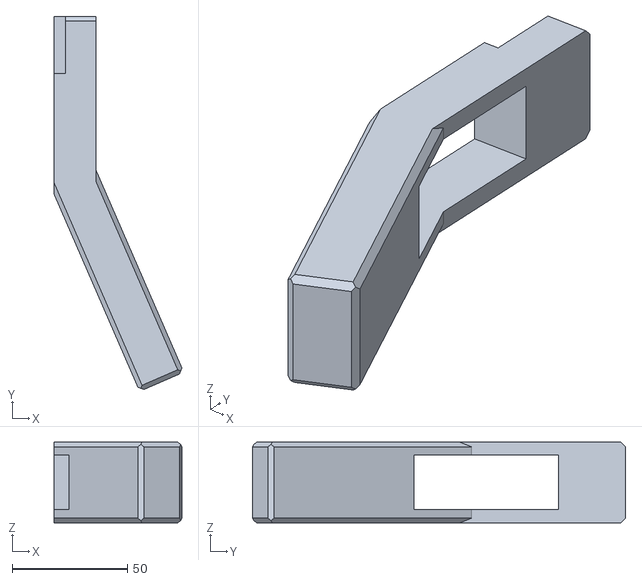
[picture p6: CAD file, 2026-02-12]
CADFiles/LiDAR_Handle.stl
55.5 x 161.7 x 35.0

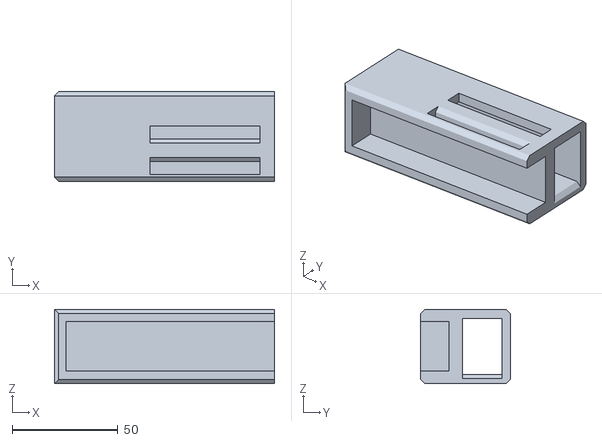
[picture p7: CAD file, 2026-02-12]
CADFiles/LiDAR_Front.stl
104.0 x 42.5 x 35.0

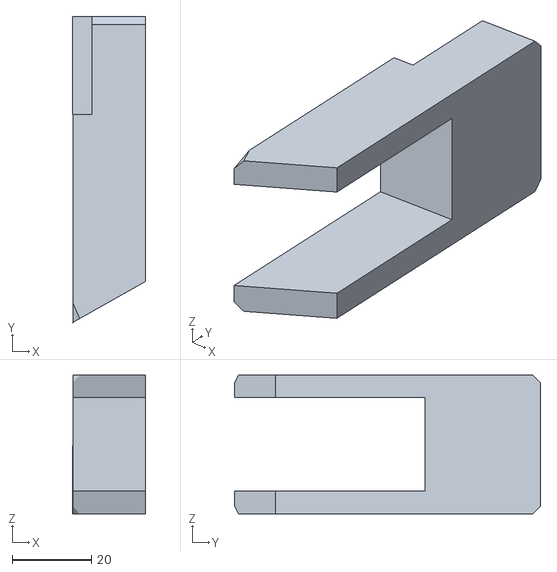
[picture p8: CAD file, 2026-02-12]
CADFiles/LiDAR_HandleTop.stl
18.3 x 77.1 x 35.0

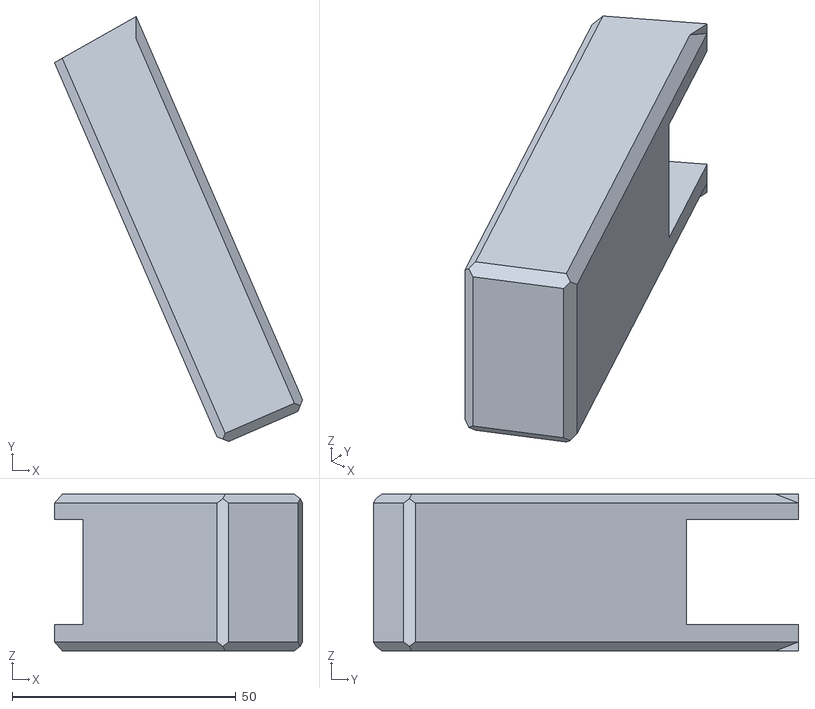
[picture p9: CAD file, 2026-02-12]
CADFiles/LiDAR_HandelBottom.stl
55.4 x 95.0 x 35.0

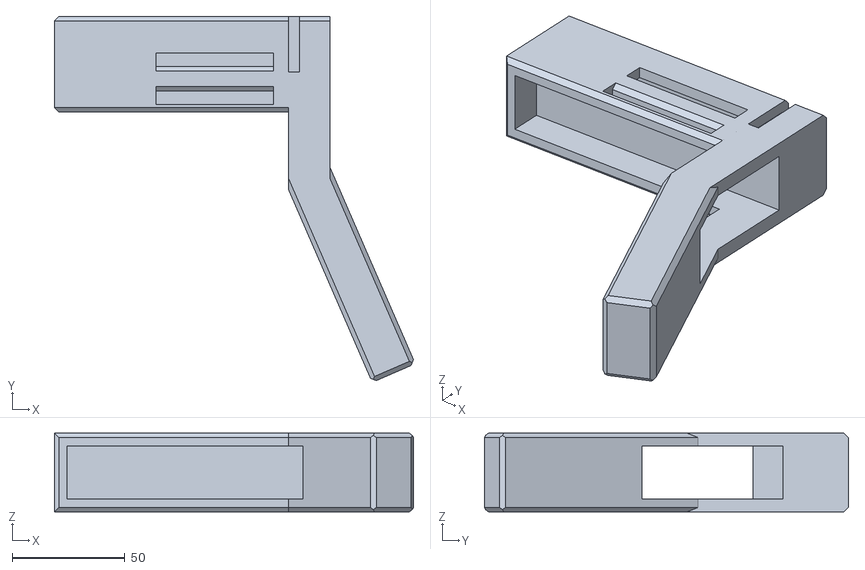
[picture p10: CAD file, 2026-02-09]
CADFiles/LiDAR_Housing.stl
159.4 x 161.7 x 35.0

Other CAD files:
CADFiles/LiDAR_Housing.3dm

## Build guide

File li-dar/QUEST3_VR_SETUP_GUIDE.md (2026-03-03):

# Godot Quest 3 VR LiDAR Point Cloud Setup Guide

## Overview
This Godot 4.x project provides a VR-based LiDAR point cloud visualization system for Meta Quest 3. It uses Quest 3 positional tracking to create accurate point cloud visualizations in VR with a black background.

## What This Setup Does
- Receives LiDAR data via UDP (TFLuna distance sensor + BNO055 orientation)
- Visualizes real-time point clouds in VR with color-coded distance
- Uses Quest 3's superior tracking for accurate spatial mapping
- Provides VR controller-based navigation and point cloud manipulation
- Supports spatial deduplication for cleaner point clouds
- Renders up to 50,000 points with optimized mesh-based rendering

---

## Prerequisites

### Hardware
- **Meta Quest 3** VR headset
- **TFLuna LiDAR sensor** (connected to your PC/Raspberry Pi)
- **BNO055 IMU sensor** (for orientation data)
- **PC with WiFi/USB connection** to Quest 3

### Software
- **Godot 4.3+** (download from godotengine.org)
- **Android SDK and NDK** (for Quest 3 builds)
- **OpenXR support** (included in Godot 4+)
- **Python 3.x** (for sensor data streaming)
- **ADB (Android Debug Bridge)** (for deploying to Quest 3)

---

## Part 1: Install Godot and Android Export Templates

### Step 1.1: Download Godot
1. Go to https://godotengine.org/download
2. Download **Godot 4.3 Standard** (not .NET version)
3. Extract and run `Godot_v4.3-stable_win64.exe`

### Step 1.2: Install Android Export Templates
1. In Godot, go to **Editor → Manage Export Templates**
2. Click **Download and Install**
3. Wait for templates to download (this may take several minutes)

### Step 1.3: Configure Android SDK
1. Go to **Editor → Editor Settings**
2. Navigate to **Export → Android**
3. Set paths:
   - **Android SDK Path**: `C:\Users\YourName\AppData\Local\Android\Sdk`
   - **Debug Keystore**: Auto-generated or use existing
   
   If you don't have Android SDK installed:
   - Download Android Studio from https://developer.android.com/studio
   - Install Android Studio and open it
   - Go to **Tools → SDK Manager**
   - Install **Android SDK Platform-Tools** and **NDK**

---

## Part 2: Open the Project

### Step 2.1: Launch Godot
1. Open **Godot 4.3**
2. Click **Import**
3. Navigate to: `C:\Users\lpcoo\OneDrive\Desktop\Capstone Project - LiDAR\li-dar`
4. Select `project.godot`
5. Click **Import & Edit**

### Step 2.2: Verify Project Structure
In the **FileSystem** panel, you should see:
```
li-dar/
├── materials/
│   └── point_cloud_material.tres
├── scenes/
│   └── main_vr.tscn
├── scripts/
│   ├── lidar_udp_receiver.gd
│   ├── point_cloud_visualizer.gd
│   └── vr_controller.gd
└── shaders/
    └── point_cloud.gdshader
```

---

## Part 3: Configure Quest 3 Export Settings

### Step 3.1: Create Android Export Preset
1. Go to **Project → Export**
2. Click **Add...** → **Android**
3. Name it: `Quest 3`

### Step 3.2: Configure Export Options
In the Export window, set:

**Options Tab:**
- **Name**: `LiDAR VR Point Cloud`
- **Runnable**: ✓ (checked)

**Resources Tab:**
- **Export Mode**: Export all resources

**Features Tab:**
- Custom Build: Use Custom Build (Optional, for plugins)

**Permissions Tab:**
Enable these permissions:
- ✓ INTERNET
- ✓ ACCESS_NETWORK_STATE
- ✓ ACCESS_WIFI_STATE

**XR Features Tab:**
- **XR Mode**: OpenXR
- **Hand Tracking**: V2.0 (Quest 3 feature)
- **Passthrough**: Disabled
- **Foveation Level**: High (for performance)

### Step 3.3: Set Android Manifest
In **Android → Manifest** section, add:
```xml
<category android:name="com.oculus.intent.category.VR" />
<uses-feature android:name="android.hardware.vr.headtracking" android:version="1" android:required="true" />
```

---

## Part 4: Configure Python UDP Streaming

### Step 4.1: Ensure Python Scripts are Running
Your existing Python scripts should be streaming data. Verify they're running:

```powershell
cd "C:\Users\lpcoo\OneDrive\Desktop\Capstone Project - LiDAR"
python tools/send_sensor_data_udp.py
```

Or run all components:
```powershell
python run_all_components.py
```

### Step 4.2: Configure Network Settings
**Important**: Quest 3 and PC must be on the same WiFi network!

1. Get your PC's IP address:
   ```powershell
   ipconfig
   ```
   Look for **IPv4 Address** (e.g., `192.168.1.100`)

2. Update the UDP destination in your Python script to broadcast:
   ```python
   UDP_IP = "0.0.0.0"  # Listen on all interfaces
   UDP_PORT = 5005
   ```

### Step 4.3: Configure Firewall
Allow UDP port 5005 through Windows Firewall:

```powershell
netsh advfirewall firewall add rule name="LiDAR UDP" dir=in action=allow protocol=UDP localport=5005
```

---

## Part 5: Testing in Godot Editor (PC VR Preview)

### Step 5.1: Test Without VR First
1. In Godot, open `scenes/main_vr.tscn`
2. Press **F5** or click **Run Project**
3. You should see the scene load (no VR yet)
4. Check the **Output** panel for:
   ```
   ✓ UDP Receiver started on port 5005
   ✓ Point Cloud Visualizer connected to UDP Receiver
   ```

### Step 5.2: Verify UDP Reception
1. Start your Python sensor streaming script
2. Watch the **Output** panel for incoming packets
3. You should see points appearing in the viewport

---

## Part 6: Deploy to Quest 3

### Step 6.1: Enable Developer Mode on Quest 3
1. Open **Meta Quest mobile app** on your phone
2. Go to **Menu → Devices → Quest 3**
3. Select **Developer Mode**
4. Toggle **Developer Mode ON**

### Step 6.2: Connect Quest 3 to PC
1. Connect Quest 3 to PC via **USB-C cable**
2. Put on the headset
3. You'll see a prompt: **Allow USB debugging?** → Select **Always Allow**

### Step 6.3: Verify ADB Connection
Open PowerShell and run:
```powershell
adb devices
```

You should see:
```
List of devices attached
1WMHH1234567    device
```

### Step 6.4: Export and Install
1. In Godot, go to **Project → Export**
2. Select **Quest 3** preset
3. Click **Export Project**
4. Choose a location and filename: `lidar_quest3.apk`
5. Click **Save**

Or **Remote Deploy**:
1. With Quest 3 connected, click **Remote Debug** or **Export → Install & Run**
2. The app will install and launch automatically

---

## Part 7: Using the App on Quest 3

### Controls

**Left Controller (Thumbstick):**
- **Up/Down**: Move forward/backward
- **Left/Right**: Strafe left/right

**Right Controller:**
- **Thumbstick Left/Right**: Rotate view
- **Grip + Trigger**: Scale point cloud size
- **A Button**: Toggle spatial deduplication
- **B Button**: Clear point cloud

**Both Controllers:**
- Walk around to see the point cloud from different angles
- Quest 3's tracking provides accurate positioning

### What You Should See
1. Point cloud appears in 3D space
2. Points are color-coded:
   - **Blue**: Close objects (< 1m)
   - **Red**: Far objects (> 4m)
   - **Green/Yellow**: Mid-range
3. Brighter points = stronger signal
4. Smooth, real-time updates

---

## Part 8: Optimization and Troubleshooting

### Performance Optimization

**If framerate is low:**
1. Open `scenes/main_vr.tscn`
2. Select **PointCloudVisualizer** node
3. In Inspector, reduce:
   - **Max Points**: 30000 (from 50000)
   - **Voxel Size**: 0.05 (from 0.03)

**Enable Fixed Foveated Rendering:**
- Already enabled in project.godot
- Quest 3 will render center of view at higher quality

### Common Issues

**Issue: "No UDP packets received"**
- Verify PC and Quest 3 are on same WiFi
- Check Windows Firewall allows UDP 5005
- Ensure Python script is running
- Try increasing UDP send rate in Python

**Issue: "App crashes on Quest 3"**
- Check Godot output for errors before exporting
- Ensure Android export templates are installed
- Verify OpenXR is enabled in export settings
- Check Quest 3 has latest firmware

**Issue: "Point cloud is jittery"**
- Increase **Orientation Smoothing** (0.5 → 0.8)
- Increase **Distance Median Window** (5 → 10)
- Check BNO055 calibration

**Issue: "Colors look wrong"**
- Adjust **Min Color** and **Max Color** in visualizer
- Check **Min/Max Distance Meters** range
- Verify TFLuna is reporting correct distances

**Issue: "Too many duplicated points"**
- Enable **Use Spatial Deduplication**
- Decrease **Voxel Size** (0.03 → 0.02)

---

## Part 9: Customization

### Adjust Point Size
Edit `shaders/point_cloud.gdshader`:
```gdshader
uniform float point_size : hint_range(1.0, 20.0) = 12.0;  // Increase for bigger points
```

### Change Color Scheme
Edit `scripts/point_cloud_visualizer.gd`:
```gdscript
@export var min_color: Color = Color(0.0, 1.0, 0.0)  # Green for close
@export var max_color: Color = Color(1.0, 1.0, 0.0)  # Yellow for far
```

---

## Advantages Over PiCam 3 Approach

1. **Superior Tracking**: Quest 3's inside-out tracking is more accurate than BNO055 alone
2. **6DOF Movement**: Full positional + rotational tracking
3. **Real-time Visualization**: See the point cloud immediately in VR
4. **Interactive**: Walk around and manipulate the point cloud in real-time
5. **No Camera Processing**: No need for Aruco markers or camera calibration
6. **Higher Refresh Rate**: Quest 3 runs at 90Hz or 120Hz
7. **Built-in Display**: No need for external monitor

---

## Next Steps

1. **Calibrate Sensors**: Run calibration scripts for BNO055 and TFLuna
2. **Save Point Clouds**: Add export functionality to save point clouds as PLY/OBJ files
3. **Multi-Sensor Support**: Add support for multiple TFLuna sensors
4. **Hand Tracking**: Use Quest 3's hand tracking instead of controllers
5. **Spatial Anchors**: Save point clouds with persistent world anchors

---

## File Reference

- **main_vr.tscn**: Main VR scene with XR setup
- **lidar_udp_receiver.gd**: Receives and parses UDP packets
- **point_cloud_visualizer.gd**: Creates and updates point cloud mesh
- **vr_controller.gd**: Handles Quest 3 controller input
- **point_cloud.gdshader**: Custom shader for point rendering
- **point_cloud_material.tres**: Material using the custom shader

---

## Support and Resources

- **Godot XR Documentation**: https://docs.godotengine.org/en/stable/tutorials/xr/
- **Quest 3 Development**: https://developer.oculus.com/documentation/
- **Project Issues**: Check DIARY.md for development notes

---

**Happy VR Point Cloud Mapping! 🚀**

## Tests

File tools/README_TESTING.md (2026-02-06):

Pi Sensor Test Instructions
===========================

Quick instructions to install prerequisites and run the per-device tests on a Raspberry Pi.

Prerequisites (Raspberry Pi OS):

- Enable I2C and Serial and Camera (use `raspi-config` UI).
- Update system and install OS packages for camera/OpenCV:

```bash
sudo apt update
sudo apt install -y python3-pip python3-opencv python3-picamera2
```

- Install Python dependencies from the repository:

```bash
pip3 install --user -r requirements.txt
```

Hardware notes:
- BNO055: connected via I2C (SDA, SCL). Default address 0x28.
- TF-Luna: connected via UART (e.g., /dev/serial0). Default 115200 baud.
- Camera: Pi Camera 3 or compatible (Picamera2).

Running tests
-------------

Run all tests sequentially (each for 10 seconds by default):

```bash
python3 tools/run_all_tests.py --all --duration 10
```

Run a single test (examples):

```bash
# Capture a camera image
python3 tools/run_all_tests.py --camera --duration 5 --camera-output test.jpg

# Read BNO055 for 20 seconds
python3 tools/run_all_tests.py --bno --duration 20 --bno-address 0x28

# Read TF-Luna on serial port
python3 tools/run_all_tests.py --tfluna --duration 15 --tfluna-port /dev/serial0

# Run only ArUco detection (provide --calib if you have calibration .npz)
python3 tools/run_all_tests.py --aruco --duration 15 --marker-length 0.05 --calib camera_calib.npz
```

Outputs
-------

All textual outputs are written to `test_outputs/` by default. Camera images are saved there as well.

If something fails, please paste the `test_outputs/*.txt` logs and I can help interpret them.

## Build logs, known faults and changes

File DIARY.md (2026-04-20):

# Project Diary
## (2/5/26)
## What I want to add
- BNO055 IMU
- Pi Camera 3
- Jumper cables

## What I have added
- TF-Luna LiDAR scanner
- Raspberry Pi 5

## Notes
- Plan: assemble scanner system after the BNO055 IMU, Pi Camera 3, and jumper cables arrive.
- Software choice: Raspberry Pi will handle point-generation math, then send point data to Godot for visualization.
- Orientation plan: use BNO055 quaternion output for more accurate orientation tracking.
- Camera plan: use Pi Camera 3 with marker-based localization to reduce drift when mapping.

## (2/6/26)

## What I want to add 
- 3D printed casing
- software for part integration

## What I have added
- BNO055 IMU
- Pi Camera 3
- Jumper cables
- TF-Luna LiDAR scanner
- Raspberry Pi 5

## Notes
- Plan: I have wired in all parts so now my game plan is to test and calibrate all parts to get some preliminary test data. Then I'll begin working on the housing for all my parts to make it into a handheld device. Then I will work further on the software.
- Now that all components have been tested and are working I have made a working dev branch where I will develope the software to make 3D maps and create the housing for the full system.

## (2/9/26)

##
- Plan: I have begon designing and printing the housing for the LiDAR system. While the case is being printed I plan on working on building the bridge of data between the hardware and software. I have chosen to send the readings of the TF-luna and other components to a 3D environment made in Unity.

## (2/12/26)
### What I accomplished
- Finished Pi Camera 3 testing and calibration.
- Successfully estimated ArUco marker poses and streamed them to Unity.
- Updated Unity receiver to handle both sensor and marker pose data.
- Cleaned up unused folders (libcamera) from git tracking.

### Next Steps
- Commit and push latest changes.
- Continue testing marker pose visualization in Unity.
- Finalize integration and document workflow.

## (3/3/26)
### What I accomplished
- Switched focus from Unity-only visualization to a dedicated Godot VR pipeline for Quest 3.
- Set up the `li-dar/` Godot project structure for VR point cloud rendering.
- Added initial VR scripts for UDP receive, point cloud visualization, and controller input.
- Added project setup docs for Quest 3 deployment and testing.

### Next Steps
<<<<<<< Updated upstream
- Validate full sensor-to-VR data flow (TFLuna + BNO055 -> UDP -> Quest 3 app).
- Tune rendering and point density to keep stable FPS in-headset.
- Continue documenting setup and troubleshooting notes.

## (3/10/26)
### What I added
- Godot Quest 3 VR app assets and config in `li-dar/` (scene, scripts, shaders, materials, Android export files).
- VR-specific scripts: `vr_init.gd`, `vr_hud_3d.gd`, and `debug_hud.gd` for startup and in-headset debugging.
- Quest 3 deployment docs: `li-dar/QUEST3_VR_SETUP_GUIDE.md`, `li-dar/QUEST3_QUICK_START.md`, and `li-dar/deploy_to_quest3.ps1`.
- Updated point cloud shader/material pipeline for better in-headset visualization.

### Notes
- Current visualization direction is Quest 3 VR-first (black background, non-passthrough) so scanning can be viewed in an isolated environment.
- Python tooling and HAL remain the sensor source, with UDP bridging into the VR app.

### Next Steps
- Run end-to-end headset test with live UDP stream and record performance baseline.
- Add save/export option for captured point clouds.
- Refine VR interaction flow (controller toggles, reset, and debug HUD controls).

## (3/23/26)
### What I accomplished
- Fixed point cloud coordinate orientation in Unity (`LidarUdpReceiver.cs`) — point cloud now renders in first-person perspective instead of top-down.
- Resolved left-right mirroring issue: scanner movement to the left now correctly plots points to the left.
- Fine-tuned yaw correction offset iteratively from 90° → -90° → -135° → -180° based on live testing feedback.
- Added right-click mouse drag orbit feature, allowing the camera to rotate around the point cloud interactively.
- Fixed a Unity runtime crash (`InvalidOperationException`) caused by legacy `Input.*` API calls conflicting with the project's new Input System package — patched `HandleRightClickOrbit()` with a `#if ENABLE_INPUT_SYSTEM` / `#else` dual-path implementation using `Mouse.current`.

### Current Working Settings (Unity Inspector)
- Flip X: false, Flip Y: true
- Swap Y And Z: true, Invert Z: true, Mirror Horizontal: true
- Yaw Correction Degrees: -180
- Enable Right Click Orbit: true, Orbit Sensitivity: 3.0

### Next Steps
- Run a full live scan test end-to-end (Pi → UDP → Unity) to validate orientation and controls.
- Consider adding mouse wheel zoom and middle-click pan for fuller view control.

## Presentation Out line (3/10/26)
- Intro - begin by defining LiDAR and its uses
- Build components - list out components used and then describe their various functions
- Construction - describe the construction of the LiDAR scanner (wiring into the Raspberry Pi, CAD modeling, and printing/assembly.
- Initial testing - talk about the raw data derived from each component
- Sending data - talk about using UDP to send packets of data from the initial testing to the Unity/Godot environments
- Point cloud - talk about generating point clouds from the data sent over from the scanner via UDP
- VR capabilities - talk about how now that point clouds have been generated via a 2D interface like unity it can now be integrated with VR to make a more interactive point cloud with greater accuracy.
- Conclusion - describe how point clouds can be useful and my overall experience building the LiDAR scanner system.

## (4/6/26)
### Notes
- After further research, I found that the only reliable way to get proper close-up object scans is through the ArUco process using the Pi Camera 3.
- With more work on the framework, I can get this workflow fully functional.
- Current blocker: my Pi Camera 3 is still not working.

### Next Steps
- Purchase and install a replacement Pi Camera 3.
- Resume and complete the small object scanning workflow once the new camera is in place.
=======
- 
- 
- 

## (4/13/26)
### What I accomplished
- Replaced Pi Camera 3 with Pi Camera Rev 1.3 and verified camera is working.
### Plan / Next Steps (focus shift to ArUco)
- Use ArUco markers for more accurate positioning and pointcloud alignment.
- Capture new calibration images with the Rev 1.3 camera and run camera calibration.
- Update ArUco scripts (`tools/aruco_pose_demo.py`, `tools/aruco_anchor_publisher.py`) to use the new calibration and camera device/backend.
- Generate improved point clouds using marker-based poses and evaluate accuracy.
- Print a set of ArUco markers for field testing and repeat calibration if needed.

### Notes
- Will prefer OpenCV VideoCapture or `picamera2` depending on environment; test both if necessary.
- Next immediate action: capture calibration images and produce a `.npz` intrinsics file.
>>>>>>> Stashed changes

## (4/20/26)
### What I accomplished
- Updated BNO055 I2C usage to default to bus 3 and added `--i2c-bus` to relevant tools.
- Integrated ArUco marker output with the UDP sensor sender: `tools/send_sensor_data_udp.py` now listens for ArUco packets (default port 6006) and includes marker data in outgoing UDP packets to Unity.
- Made ArUco detector UDP destination configurable (`tools/aruco_pose_demo.py` now defaults to sending to localhost:6006).

### Final status (4/20/26, after live testing)
- Rewired BNO055 to I2C bus 1 and updated defaults to use bus 1. All IMU reads validated on bus 1.
- Started headless ArUco detector (Picamera2) feeding the local aggregator on port 6006.
- Implemented a simple `scanner_pose` fusion in `tools/send_sensor_data_udp.py` combining ArUco position (first marker `tvec`) with BNO055 orientation (normalized quaternion). Outgoing UDP packets now include `scanner_pose` with `position` and `orientation` fields.
- Verified outgoing UDP packets to Unity (192.168.0.198:5005) contain `tfluna`, `bno055`, `aruco`, and the new `scanner_pose` field.

### Next steps / Improvements to consider
- Smooth `scanner_pose` over time (exponential moving average or complementary filter).
- Transform ArUco `tvec` from camera frame into the IMU/world frame using measured extrinsics.
- Average or robustly select among multiple detected markers for a more stable position.
- Add timestamp alignment logic and small buffer to better fuse asynchronous sensor updates.
- Add a `--fusion-mode` flag to `tools/send_sensor_data_udp.py` to toggle simple vs. smoothed fusion.

### Next steps / Test plan
- Run the ArUco detector and the sensor UDP sender together: start `tools/send_sensor_data_udp.py` (pointing to Unity IP) and run `tools/aruco_pose_demo.py` to feed marker data to it.
- Verify fused packets arriving in Unity contain `aruco` field with markers and that IMU/TF-Luna fields remain present.
- If OK, perform a live scan and note results in this diary.

### Notes
- Defaults were set to I2C bus 3 to match the new hardware wiring; use `--i2c-bus` to override if needed.

### Additional work completed later on 4/20/26
- Fixed an unexpected Unity startup sphere by preventing runtime marker visualization from spawning the point prefab unless marker rendering is explicitly enabled.
- Moved mesh initialization earlier in the Unity lifecycle so the receiver no longer flashes a primitive mesh at startup.
- Refactored the sensor-to-Unity frame handling so `tools/send_sensor_data_udp.py` now owns the main coordinate conversion and tags outgoing packets as Unity-frame data.
- Simplified `Assets/Scripts/LidarUdpReceiver.cs` so Unity consumes already-converted packet data instead of relying on stacked flip/swap corrections.
- Added Unity-frame trim and inversion controls for fast live testing while keeping the legacy correction path separated.
- Added debug overlay lines in Unity to show `Position source`, `Frame mode`, and `Pose mode` during live tests.
- Fixed a regression where valid `pos_m` endpoint data could be skipped, causing a blank view even though UDP packets were arriving.
- Corrected the scanner semantics so tracked ArUco pose is treated as the scanner origin and the actual plotted point is the measured endpoint in front of the scanner.
- Resolved the "horizontal cylinder around the user" issue by preferring endpoint data (`pos_m`) over scanner origin data when plotting the point cloud.

### Current understanding after live testing on 4/20/26
- ArUco markers are actively used when the camera-side detector is running and sending packets into `tools/send_sensor_data_udp.py` on the configured ArUco UDP port.
- ArUco improves accuracy by providing a tracked scanner origin that reduces IMU-only drift and makes first-person room/object scanning more reliable.
- If ArUco is not available, the system falls back to IMU orientation plus TF-Luna distance, which is enough for orientation-driven plotting but is less accurate for real spatial alignment.

### Next steps after today's fixes
- Run another live scan with ArUco visible in the camera feed and confirm the Unity overlay reports the expected position source and pose mode.
- Measure and tune the physical beam/mount alignment only if remaining error is consistent after ArUco-assisted scanning.
- Once the scan behavior is stable, remove or hide the remaining legacy Unity correction controls to reduce misconfiguration risk.

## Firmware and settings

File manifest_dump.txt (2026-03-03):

N: android=http://schemas.android.com/apk/res/android
  E: manifest (line=2)
    A: android:versionCode(0x0101021b)=(type 0x10)0x1
    A: android:versionName(0x0101021c)="1.0" (Raw: "1.0")
    A: android:installLocation(0x010102b7)=(type 0x10)0x0
    A: android:compileSdkVersion(0x01010572)=(type 0x10)0x23
    A: android:compileSdkVersionCodename(0x01010573)="15" (Raw: "15")
    A: package="com.godotengine.lidarvr" (Raw: "com.godotengine.lidarvr")
    A: platformBuildVersionCode=(type 0x10)0x23
    A: platformBuildVersionName=(type 0x10)0xf
    E: uses-sdk (line=8)
      A: android:minSdkVersion(0x0101020c)=(type 0x10)0x18
      A: android:targetSdkVersion(0x01010270)=(type 0x10)0x21
    E: supports-screens (line=12)
      A: android:smallScreens(0x01010284)=(type 0x12)0xffffffff
      A: android:normalScreens(0x01010285)=(type 0x12)0xffffffff
      A: android:largeScreens(0x01010286)=(type 0x12)0xffffffff
      A: android:xlargeScreens(0x010102bf)=(type 0x12)0xffffffff
    E: uses-feature (line=18)
      A: android:glEsVersion(0x01010281)=(type 0x11)0x30000
      A: android:required(0x0101028e)=(type 0x12)0xffffffff
    E: uses-permission (line=22)
      A: android:name(0x01010003)="android.permission.ACCESS_NETWORK_STATE" (Raw: "android.permission.ACCESS_NETWORK_STATE")
    E: uses-permission (line=23)
      A: android:name(0x01010003)="android.permission.ACCESS_WIFI_STATE" (Raw: "android.permission.ACCESS_WIFI_STATE")
    E: uses-permission (line=24)
      A: android:name(0x01010003)="android.permission.INTERNET" (Raw: "android.permission.INTERNET")
    E: uses-feature (line=26)
      A: android:name(0x01010003)="android.hardware.vulkan.level" (Raw: "android.hardware.vulkan.level")
      A: android:required(0x0101028e)=(type 0x12)0x0
      A: android:version(0x01010519)=(type 0x10)0x1
    E: uses-feature (line=30)
      A: android:name(0x01010003)="android.hardware.vulkan.version" (Raw: "android.hardware.vulkan.version")
      A: android:required(0x0101028e)=(type 0x12)0xffffffff
      A: android:version(0x01010519)=(type 0x11)0x400003
    E: uses-permission (line=36)
      A: android:name(0x01010003)="org.khronos.openxr.permission.OPENXR" (Raw: "org.khronos.openxr.permission.OPENXR")
    E: uses-permission (line=37)
      A: android:name(0x01010003)="org.khronos.openxr.permission.OPENXR_SYSTEM" (Raw: "org.khronos.openxr.permission.OPENXR_SYSTEM")
    E: queries (line=39)
      E: provider (line=40)
        A: android:authorities(0x01010018)="org.khronos.openxr.runtime_broker;org.khronos.openxr.system_runtime_broker" (Raw: "org.khronos.openxr.runtime_broker;org.khronos.openxr.system_runtime_broker")
      E: intent (line=42)
        E: action (line=43)
          A: android:name(0x01010003)="org.khronos.openxr.OpenXRRuntimeService" (Raw: "org.khronos.openxr.OpenXRRuntimeService")
      E: intent (line=45)
        E: action (line=46)
          A: android:name(0x01010003)="org.khronos.openxr.OpenXRApiLayerService" (Raw: "org.khronos.openxr.OpenXRApiLayerService")
    E: uses-feature (line=50)
      A: android:name(0x01010003)="android.hardware.vr.headtracking" (Raw: "android.hardware.vr.headtracking")
      A: android:required(0x0101028e)=(type 0x12)0x0
      A: android:version(0x01010519)=(type 0x10)0x1
    E: application (line=55)
      A: android:label(0x01010001)=@0x7f0b0004
      A: android:icon(0x01010002)=@0x7f0a0000
      A: android:debuggable(0x0101000f)=(type 0x12)0xffffffff
      A: android:allowBackup(0x01010280)=(type 0x12)0x0
      A: android:isGame(0x010103f4)=(type 0x12)0xffffffff
      A: android:extractNativeLibs(0x010104ea)=(type 0x12)0x0
      A: android:appCategory(0x01010545)=(type 0x10)0x0
      A: android:appComponentFactory(0x0101057a)="androidx.core.app.CoreComponentFactory" (Raw: "androidx.core.app.CoreComponentFactory")
      A: android:hasFragileUserData(0x0101059a)=(type 0x12)0x0
      A: android:requestLegacyExternalStorage(0x01010603)=(type 0x12)0x0
      E: meta-data (line=66)
        A: android:name(0x01010003)="org.godotengine.rendering.method" (Raw: "org.godotengine.rendering.method")
        A: android:value(0x01010024)="mobile" (Raw: "mobile")
      E: meta-data (line=69)
        A: android:name(0x01010003)="org.godotengine.editor.version" (Raw: "org.godotengine.editor.version")
        A: android:value(0x01010024)="4.6.1.stable" (Raw: "4.6.1.stable")
      E: activity (line=73)
        A: android:theme(0x01010000)=@0x7f0c0009
        A: android:name(0x01010003)="com.godot.game.GodotApp" (Raw: "com.godot.game.GodotApp")
        A: android:exported(0x01010010)=(type 0x12)0x0
        A: android:excludeFromRecents(0x01010017)=(type 0x12)0x0
        A: android:launchMode(0x0101001d)=(type 0x10)0x4
        A: android:screenOrientation(0x0101001e)=(type 0x10)0x0
        A: android:configChanges(0x0101001f)=(type 0x11)0x3ff4
        A: android:windowSoftInputMode(0x0101022b)=(type 0x11)0x10
        A: android:resizeableActivity(0x010104f6)=(type 0x12)0xffffffff
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

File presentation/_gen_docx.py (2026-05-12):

"""Generate trifold_board.docx from the 8 talking-point sections."""
from docx import Document
from docx.shared import Pt, RGBColor, Inches, Cm
from docx.enum.text import WD_ALIGN_PARAGRAPH
from docx.enum.section import WD_ORIENT
from docx.oxml.ns import qn
from docx.oxml import OxmlElement
import copy

doc = Document()

# ── Page setup: landscape letter ──────────────────────────────────────────────
section = doc.sections[0]
section.orientation = WD_ORIENT.LANDSCAPE
section.page_width  = Inches(11)
section.page_height = Inches(8.5)
section.top_margin    = Inches(0.6)
section.bottom_margin = Inches(0.5)
section.left_margin   = Inches(0.7)
section.right_margin  = Inches(0.7)

# ── Styles helpers ─────────────────────────────────────────────────────────────
def set_run_color(run, hex_str):
    r, g, b = int(hex_str[0:2],16), int(hex_str[2:4],16), int(hex_str[4:6],16)
    run.font.color.rgb = RGBColor(r, g, b)

def heading(doc, number, title, subtitle, color_hex):
    """Numbered page heading."""
    p = doc.add_paragraph()
    p.alignment = WD_ALIGN_PARAGRAPH.LEFT
    num_run = p.add_run(f"{number}  ")
    num_run.bold = True
    num_run.font.size = Pt(28)
    set_run_color(num_run, color_hex)
    title_run = p.add_run(title)
    title_run.bold = True
    title_run.font.size = Pt(22)
    set_run_color(title_run, color_hex)
    p.paragraph_format.space_after = Pt(2)

    sub = doc.add_paragraph(subtitle)
    sub.runs[0].italic = True
    sub.runs[0].font.size = Pt(11)
    set_run_color(sub.runs[0], "555555")
    sub.paragraph_format.space_after = Pt(8)

    # Divider
    div = doc.add_paragraph()
    div.paragraph_format.space_after = Pt(6)
    pPr = div._p.get_or_add_pPr()
    pBdr = OxmlElement('w:pBdr')
    bottom = OxmlElement('w:bottom')
    bottom.set(qn('w:val'), 'single')
    bottom.set(qn('w:sz'), '6')
    bottom.set(qn('w:space'), '1')
    bottom.set(qn('w:color'), color_hex)
    pBdr.append(bottom)
    pPr.append(pBdr)

def section_title(doc, text, color_hex):
    p = doc.add_paragraph()
    r = p.add_run(text.upper())
    r.bold = True
    r.font.size = Pt(10)
    set_run_color(r, color_hex)
    p.paragraph_format.space_before = Pt(6)
    p.paragraph_format.space_after = Pt(2)

def bullet(doc, text, level=0):
    p = doc.add_paragraph(style='List Bullet')
    p.paragraph_format.left_indent = Inches(0.25 + level * 0.2)
    p.paragraph_format.space_after = Pt(1)
    r = p.add_run(text)
    r.font.size = Pt(10)

def body_text(doc, text):
    p = doc.add_paragraph(text)
    p.runs[0].font.size = Pt(10)
    p.paragraph_format.space_after = Pt(4)

def callout(doc, text, color_hex):
    p = doc.add_paragraph()
    r = p.add_run(f"▶  {text}")
    r.italic = True
    r.font.size = Pt(10)
    set_run_color(r, color_hex)
    p.paragraph_format.space_before = Pt(4)
    p.paragraph_format.space_after = Pt(6)

def page_break(doc):
    doc.add_page_break()

# ══════════════════════════════════════════════════════════════════════════════
# PAGE 1 – What Is LiDAR?
# ══════════════════════════════════════════════════════════════════════════════
heading(doc, "01", "What Is LiDAR?", "Understanding the core sensing technology behind this project", "1a4fa0")

section_title(doc, "Definition", "1a4fa0")
body_text(doc, "LiDAR stands for Light Detection and Ranging. It works by emitting laser pulses and measuring the time it takes for each pulse to bounce back from a surface. That travel time is converted into a precise distance measurement — the same principle as sonar, but using light instead of sound.")

section_title(doc, "How a Distance Reading Becomes a 3D Point", "1a4fa0")
for item in [
    "The sensor fires a laser and measures the round-trip time to the target.",
    "Distance (d) is calculated:  d = (c × t) / 2",
    "An orientation reading (from the IMU) provides a direction vector.",
    "Together they place a point in 3D space: (x, y, z)",
    "Thousands of these points build a point cloud — a 3D map.",
]:
    bullet(doc, item)

section_title(doc, "Real-World Uses", "1a4fa0")
for item in ["Self-driving cars", "Robotics & navigation", "Architecture & surveying",
             "Forestry & geology", "AR/VR spatial computing", "Archaeology"]:
    bullet(doc, item)

callout(doc, "This project makes LiDAR accessible at low cost — from a $30 sensor to a live interactive 3D point cloud.", "1a4fa0")

section_title(doc, "Key Stats", "1a4fa0")
for item in ["Sample rate: 250 Hz", "Effective range: 0.2 – 8 m", "Typical accuracy: ±2 cm", "Output: 3D point cloud"]:
    bullet(doc, item)

# ══════════════════════════════════════════════════════════════════════════════
# PAGE 2 – Hardware Components
# ══════════════════════════════════════════════════════════════════════════════
page_break(doc)
heading(doc, "02", "Hardware Components", "Every physical part of the scanner and what it contributes", "0d7377")

components = [
    ("TF-Luna LiDAR",        "Measures distance via time-of-flight laser",                     "UART (serial)",   "250 Hz, 0.2–8 m; returns dist, signal strength & temp"),
    ("BNO055 IMU",           "Provides 9-DOF orientation as a quaternion for point direction", "I²C (bus 1)",     "On-board sensor fusion; outputs qw, qx, qy, qz directly"),
    ("Raspberry Pi 5",       "Central compute — reads sensors, processes data, sends UDP",     "GPIO / USB",      "Runs Python tools, hosts the HAL, streams to visualization"),
    ("Pi Camera Rev 1.3",    "Detects ArUco visual markers for precise scanner positioning",   "CSI ribbon",      "Used with OpenCV for pose estimation; replaced Pi Camera 3"),
    ("3D Printed Housing",   "Holds all electronics in a stable handheld form factor",         "—",               "Designed in Rhino 3D; maintains sensor alignment during scans"),
    ("ArUco Markers",        "Visual reference points to anchor the scanner in space",          "Camera",          "Reduce IMU drift; provide absolute position in the scene"),
]

for name, purpose, interface, detail in components:
    p = doc.add_paragraph()
    r = p.add_run(f"{name}  |  ")
    r.bold = True
    r.font.size = Pt(10)
    set_run_color(r, "0d7377")
    p.add_run(f"{purpose}   [{interface}]   {detail}").font.size = Pt(10)
    p.paragraph_format.space_after = Pt(3)

callout(doc, "Each component was validated with isolated Python test scripts before full integration — catching wiring and config issues early.", "0d7377")

section_title(doc, "Total Component Cost", "0d7377")
body_text(doc, "TF-Luna (~$30), BNO055 breakout (~$10), Raspberry Pi 5 (~$80), Pi Camera (~$25). The system proves that capable spatial scanning does not require expensive commercial hardware.")

# ══════════════════════════════════════════════════════════════════════════════
# PAGE 3 – Physical Construction
# ══════════════════════════════════════════════════════════════════════════════
page_break(doc)
heading(doc, "03", "Physical Construction", "Wiring, CAD design, 3D printing, and final assembly", "1b2a6b")
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

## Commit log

2026-02-05 Added some preliminary test scripts for each component of the LiDAR system. Updated the Readme and Diary.
2026-02-05 test txt to check if Raspberry pi can connect to my github
2026-02-05 added hardware-abstraction layer and interfaces for sensor components as well as mock classes to return rand data for testing and development.
2026-02-07 Updated the camera functionality to take pictures to establish anchors for the lidar maps
2026-02-07 Lidar scanner tests
2026-02-09 Added housing designs and UDP connection between Raspberry Pi and My pc using unity.
    [LiDAR_Housing.3dm, LiDAR_Housing.stl]
2026-02-09 camera tests
2026-02-12 New models for housing parts and updated udp sender.
    [LiDAR_Front.stl, LiDAR_HandelBottom.stl, LiDAR_Handle.stl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]
2026-02-12 camera output
2026-02-12 Calibration for the pi cam 3 and marker position data
2026-03-03 VR in progress
    [export_presets.cfg]
2026-03-03 VR Updates
    [LiDAR_Front.stl, LiDAR_HandelBottom.stl, LiDAR_Handle.stl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]
2026-03-16 Midterm Presentation materials
    [LiDAR_Housing.3dm]
2026-04-06 Camera updates in diary log
2026-04-20 Camera Updates and calibration. Aruco integration with current udp sender. Unity script update.
2026-05-12 Presentation materials
